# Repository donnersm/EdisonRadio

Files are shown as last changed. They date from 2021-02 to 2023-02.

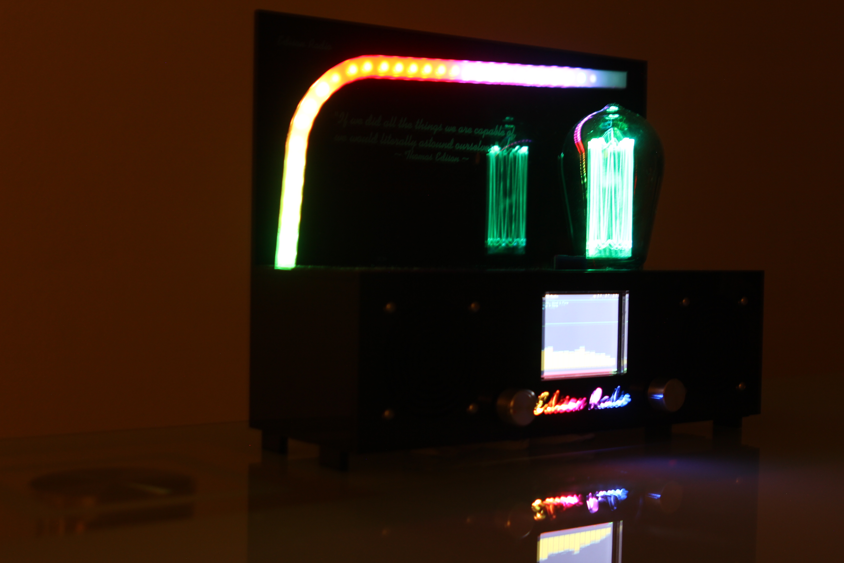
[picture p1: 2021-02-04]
Photos/IMG_9397.JPG

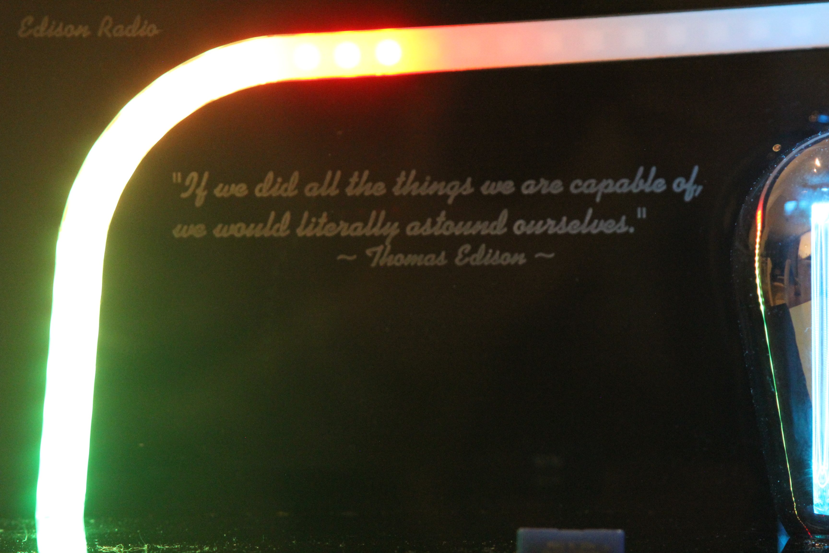
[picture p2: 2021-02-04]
Photos/IMG_9385.JPG

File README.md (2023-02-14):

# EdisonRadio
Internet Radio ESP32 based on Ed's Smallenburg's version but with some enhancements
You'll find all the information about firmware hardware, web interface, building instruction etc. in the documentation folder

If you are using the same hardware wiring as me...you can also upload the pre compiled sketch ( bin file) directly to your ESP32
https://donnersm.github.io/EdisonRadio/flash.html
Use edge or chrome browser for this to work and before you upload, run the init sketch once...

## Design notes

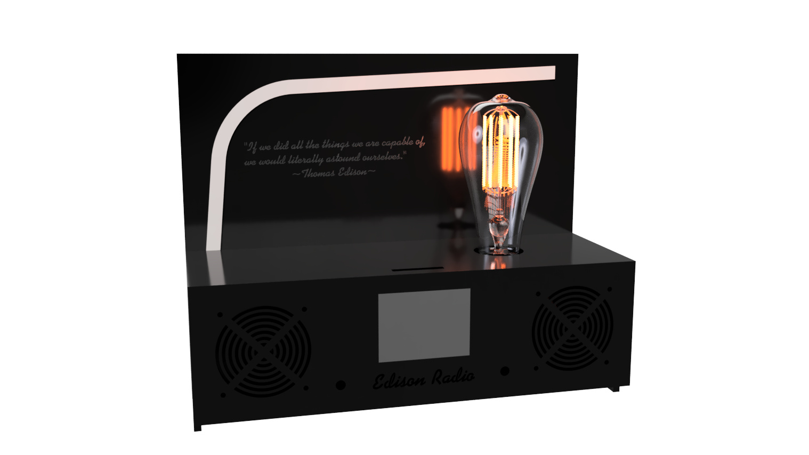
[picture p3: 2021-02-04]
Photos/radio_2021-Jan-22_03-03-24PM-000_CustomizedView857531055_jpg.jpg

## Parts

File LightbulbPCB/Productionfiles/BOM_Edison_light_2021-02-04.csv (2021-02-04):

ID | Name | Designator | Footprint | Quantity | Manufacturer Part | Manufacturer | Supplier | Supplier Part | LCSC Assembly | JLCPCB SMD
1 | WS2812B | LED1,LED2,LED3,LED4 | LED-SMD_4P-L5.0-W5.0-TL | 4 | WS2812B | Worldsemi | LCSC | C114585 | Yes
2 | 2*2P header | H1 | HDR-TH_4P-P2.54-H-R2-C2-S2.54-W10.0 | 1 | 2*2P header | BOOMELE | LCSC | C60561
3 | 100nF | C1 | C1206 | 1 | CL31B104KBCNNNC | SAMSUNG | LCSC | C24497 |  | Yes

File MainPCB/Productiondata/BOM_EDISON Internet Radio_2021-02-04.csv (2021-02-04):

ID | Name | Designator | Footprint | Quantity | Manufacturer Part | Manufacturer | Supplier | Supplier Part | JLCPCB SMD | LCSC Assembly
1 | VS1053B | U7 | LQFP-48_L7.0-W7.0-P0.50-LS9.0-BL | 1 | VS1053B | VLSI | LCSC | C9922 | Yes
2 | 22pF | C24,C25 | C0805 | 2 | CL21C220JBANNNC | SAMSUNG | LCSC | C1804 | Yes
3 | MC7805ABD2TR4G | U3 | TO-263-2_L10.0-W9.1-P5.08-LS15.2-TL | 1 | MC7805ABD2TR4G | ON | LCSC | C152462 | Yes
4 | 470uF | C9 | CAP-SMD_BD8.0-L8.3-W8.3-RD | 1 | VZH471M1CTR-0810 | LELON | LCSC | C164069 | Yes
5 | RS3MB | D1,D2 | SMB_L4.6-W3.6-LS5.3-RD | 2 | RS3MB | Shandong Jingdao Microelectronics | LCSC | C123923 | Yes
6 | 100nF | C22,C7,C11,C10,C4,C15,C16,C27,C28,C29,C31,C32,C34,C26 | C0805 | 14 | CC0805KRX7R9BB104 | YAGEO | LCSC | C49678 | Yes
7 | 100K | R19,R16,R13,R11,R12,R14,R15 | R0805 | 7 | 0805W8F1003T5E | UniOhm | LCSC | C17407 | Yes
8 | MCP1703T-3302E/MB | U5 | SOT-89-3_L4.5-W2.5-P1.50-LS4.2-BR | 1 | MCP1703T-3302E/MB | MICROCHIP | LCSC | C27287 | Yes
9 | 10uF | C3,C1 | C0805 | 2 | CL21A106KAYNNNE | SAMSUNG | LCSC | C15850 | Yes
10 | 470 | R7,R1,R4,R5 | R0805 | 4 | 0805W8F4700T5E | UniOhm | LCSC | C17710 | Yes
11 | PAM8403DR_C348830 | U8 | SOP-16_L10.3-W5.4-P1.27-LS7.8-BL | 1 | PAM8403DR | Diodes Incorporated | LCSC | C348830 | Yes
12 | 10 | R10 | R0805 | 1 | 0805W8F100JT5E | UniOhm | LCSC | C17415 | Yes
13 | kf2510_3A | H7,H6,H9,H10 | CONN-TH_3P-P2.00_KF2510_3A | 4 | kf2510_3A | BOOMELE | LCSC | C29275
14 | 22 | R8,R2 | R0805 | 2 | 0805W8F220JT5E | UniOhm | LCSC | C17561 | Yes
15 | Header-Male-2.54_1x3 | H3 | HDR-TH_3P-P2.54-V | 1 | Header2.54mm 1*3P | BOOMELE | LCSC | C49257
16 | 22272061 | H1 | CONN-TH_22272061 | 1 | 22272061 | MOLEX | LCSC | C504992
17 | DG308-2.54-04P-14-00A(H) | U2 | CONN-TH_DG308-2.54-04P-14-00A-H | 1 | DG308-2.54-04P-14-00A(H) | DEGSON | LCSC | C708735
18 | 470nF | C23,C21 | C0805 | 2 | CL21B474KBFNNNE | SAMSUNG | LCSC | C13967 | Yes
19 | 10uF | C14,C17,C18,C20,C5,C12 | CAP-SMD_L3.2-W1.6-R-RD | 6 | TAJA106K016RNJ | AVX | LCSC | C7171 | Yes
20 | 470uF | C19 | CAP-SMD_BD6.3-L6.6-W6.6-FD | 1 | VZH471M0JTR-0607 | LELON | LCSC | C134834 | Yes
21 | Header-Male-2.54_2x3 | J1 | HDR-TH_6P-P2.54-V-R2-C3-S2.54 | 1 | Header-Male-2.54_2x3 | BOOMELE | LCSC | C65114
22 | 22-27-2081 | H11 | CONN-TH_22-27-2081 | 1 | 22-27-2081 | MOLEX | LCSC | C240822
23 | Header-Male-2.54_1x1 | P1 | HDR-TH_1P-P2.54-V-M | 1 | Header-Male-2.54_1x1 | ReliaPro | LCSC | C81276
24 | 1M | R20 | R0805 | 1 | 0805W8F1004T5E | UniOhm | LCSC | C17514 | Yes
25 | T2A | FH1 | FUSE-TH_BD9.5-P5.08-D1.0 | 1 | 56000001009 | Littelfuse | LCSC | C142909
26 | 15 | R6 | R0805 | 1 | 0805W8F150JT5E | UniOhm | LCSC | C17480 | Yes
27 | ESP32_DevKit_V1_DOIT-ESP32_DevKit_V1_DOIT | U1 | ESP32_DEVKIT_V1_DOIT | 1
28 | EE14 | L2,L1 | EE14_TRANSFORMER | 2 | EE14 | Unknown | Alieexpress | EE14
29 | KF128-2.54-2P | U4 | CONN-TH_P2.54_KF128-2.54-2P | 1 | KF128-2.54-2P | Cixi Kefa Elec | LCSC | C474920
30 | Header-Male-2.54_1x2 | H2,H4 | HDR-TH_2P-P2.54-V | 2 | 826629-2 | TE Connectivity | LCSC | C86471
31 | 10K | R9,R3,R18,R17 | R0805 | 4 | 0805W8F1002T5E | UniOhm | LCSC | C17414 | Yes
32 | MCP1700T-1802E/TT | U6 | SOT-23-3_L2.9-W1.3-P1.90-LS2.4-BR | 1 | MCP1700T-1802E/TT | MICROCHIP | LCSC | C150796 | Yes
33 | 47nF | C8 | C0805 | 1 | CL21B473KBCNNNC | SAMSUNG | LCSC | C53134 | Yes
34 | KF2510-5A | H8 | CONN-TH_5P-P2.54_KF2510-5A | 1 | KF2510-5A | BOOMELE | LCSC | C27544
35 | 1uF | C13 | C0805 | 1 | CL21B105KBFNNNE | SAMSUNG | LCSC | C28323 | Yes
36 | 33 | R21,R22 | R0805 | 2 | 0805W8F330JT5E | UniOhm | LCSC | C17634 | Yes | Yes
37 | 12.288MHz | X1 | HC-49S_L11.4-W4.8 | 1 | 6CS12288F20UCG | SHENZHEN CRYSTAL TECH | LCSC | C252314
38 | 10nF | C6,C2 | C0805 | 2 | CL21B103KBANNNC | SAMSUNG | LCSC | C1710 | Yes

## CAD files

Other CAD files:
Autocad/allplates.dwg
Fusion360/radio v21.f3d

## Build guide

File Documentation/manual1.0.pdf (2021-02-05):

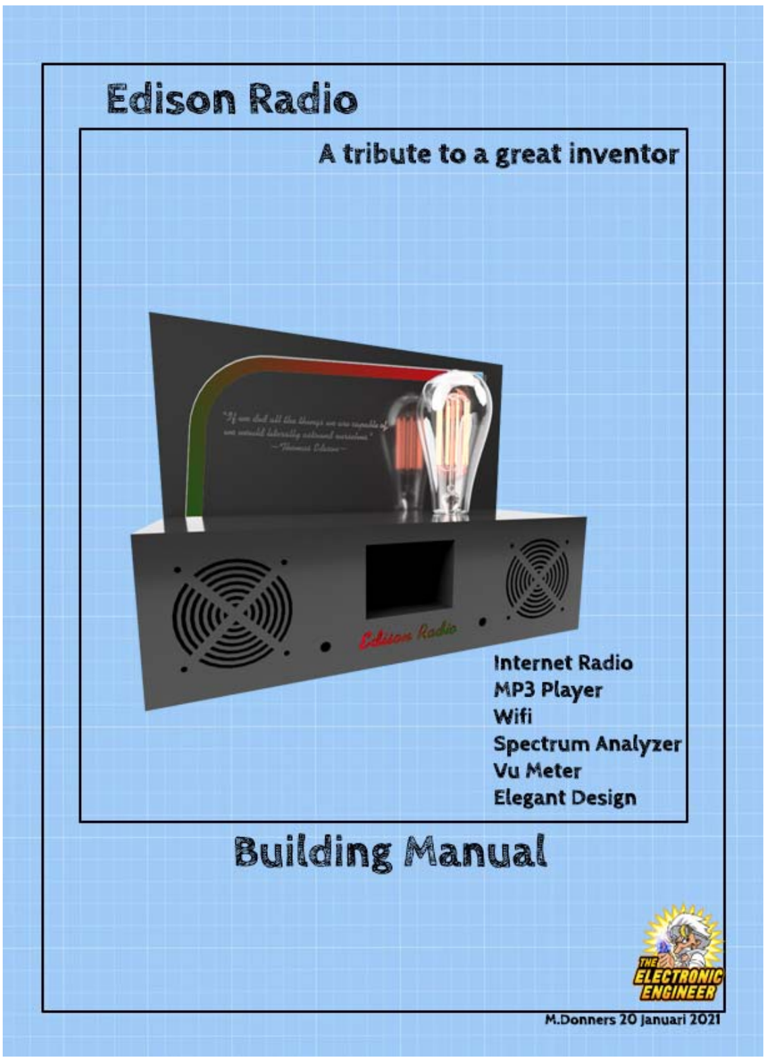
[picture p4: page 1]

## Table of Contents

M Donners Document version 1.0

## 1. Disclaimer and safety

I, Mark Donners, The Electronics Engineer, may or may not endorse various Do‐It‐Yourself (DIY) projects and all DIY projects are purely “at your own risk”. As with any DIY project, unfamiliarity with the tools and process can be dangerous. Posts should be construed as theoretical advice only.

If you are at all uncomfortable or inexperienced working on these projects (especially but not limited to electronics and mechanical), please reconsider doing the job yourself. It is very possible (but not likely) on any DIY project to damage belongings or void your property insurance, create a hazardous condition, or harm or even kill yourself or others.

I will not be held responsible for any injury due to the misuse or misunderstanding of any DIY project.

By using the information provided by me, (Website,Youtube, facebook and other social media), you agree to indemnify me, affiliates, subsidiaries and their related companies for any and all claims, damages, losses and causes of action arising out of your breach or alleged breach of this agreement(disclaimer).

The materials on this site are distributed “as is” and appear on the site without express or implied warranties of any kind, except those required by the relevant legislation. In particular, I make no warranty as to the accuracy, quality, completeness or applicability of the information provided.

The information provided is for entertainment and promotional purposes only. You may not rely on any information and opinions expressed in it for any other purpose.

Disclaimer short version:

This is a DIY project, use any provided information and/or materials at your own risk! I am not responsible for what you do with it!

## 2. About this project

This project is bases on the internet radio by Ed Smallenburg. He did an awesome job in creating a working internet‐based radio. He shared his coding and hardware on the world wide web so that people like you and me can learn from it. He shared his build on GitHub using the copyleft license. (It basically comes down to: use it, modify it as needed, don't copyright it and share….)

You can find Ed's original build and data here:

Edzelf/ESP32‐Radio: Internet radio based on ESP32, VS1053 and a TFT screen. (github.com)

So, I started with Ed's Arduino sketch and I added a few extra options:

- Search engine to find Internet Radio station by country.
- Find and implement the station's Logo and display it on the browser interface.
- Spectrum analyser on the TFT Screen
- LED VU meter with Pixel leds WS2812
- Sliders for changing Audio Settings.

The modified software and all project data will be available here:

https://github.com/donnersm/EdisonRadio

TIP: download all with one click by pressing the green button and choosing "download ZIP"

As you might have noticed, this project is named the Edison Radio. Thomas Edison was a great inventor who, amongst other things, improved the microphone for telephones by developing a carbon microphone. In ways, more than one, Edison contributed to worldwide communication. However, his greatest invention was not this carbon microphone or even his well‐known phonograph but, it was the invention of the light bulb by far! Without Edison, we might still be using candles to bring light in darkness. That is why this radio has a light bulb as centrepiece. .. O yeah, this 100% optional attribute also looks kind of cool

3. Tools needed.

You will be working with low voltage (5V max) but you should know your way around basic electronics. Using the wrong voltage or polarity might kill your project in an instance!

Being successful in building this device requires some adequate skills and tools. You should be able to solder small components on a PCB which will require a soldering station with a small tip as you will be handling components like 0805 sized and a LQFP‐48 package. If this is beyond your possibilities, then you should ask someone to do it for you or order an already assembled PCB.

(Availability will depend on demand).

Furthermore, you be programming the microcontroller by using the Arduino IDE environment. Although the steps to do so will be described in this document, it is advisable for you to get to know this Arduino software.

If you are considering building the Edison housing, you will need to produce the panels for it. It can be done by hand, but it would be best to use a Laser cutter. Remember, there are some companies that offer a laser cutting service. Maybe there is a company near you who can do it for you?

And yes, you will need some basic tools like a screwdriver

## 4. Hardware

## 4.1. Main PCB

The pcb without components is available at my Tindie store here: Tindie.

Shipping is only possible within the EU because shipping to other countries will involve import Tax, declarations of conformity and other complicated stuff. Nobody is looking for that kind of complicated formalities or import tax upon receiving the goods. If you are a resident of a country that I don’t ship to, you can always order a pcb directly from a PCB supplier near you. The Gerber productions files you need for that are available for download, although it might be more expensive than what you are hoping for. If you need 1 or 2 PCB’s, a Tindie order is the cheapest way to go.

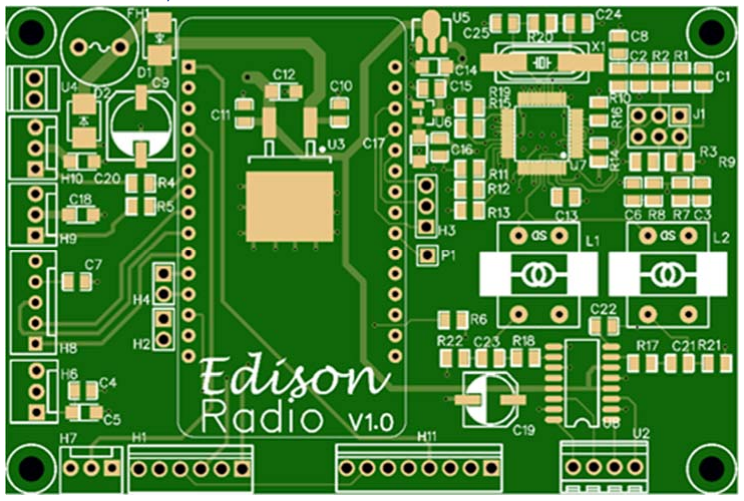
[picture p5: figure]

4.1.1. Assembly

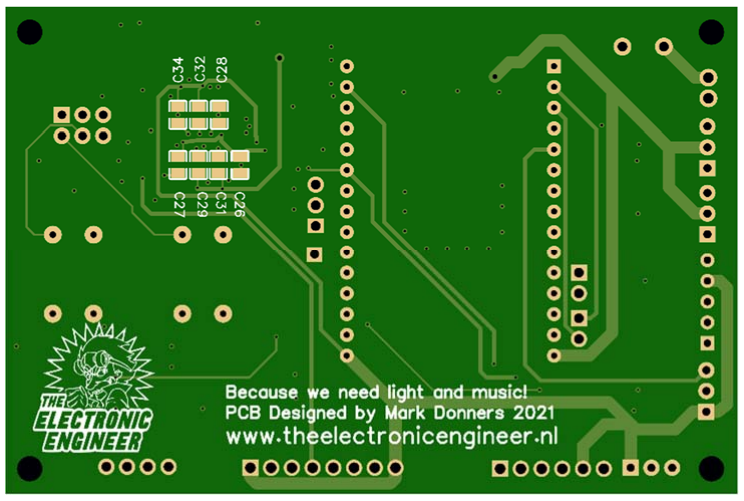
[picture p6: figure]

Assembly notes:

- Assembly of the bottom side are not that difficult all the only components on the bottom are 100nf smd 0805 capacitors (C26,27,28,29,31,32,34)
- Make sure you have the orientation of specific components correct. Resistors and ceramic capacitors are not critical but Electrolytic capacitors and semiconductors have to go on the right way! Do not mix up Cathode and Anode.
- The audio transformers L! and L2 also have an orientation. Make sure to align the letters 'SD' or dot, with the silkscreen of the PCB. WARNING, I encountered several versions that had this marking on the wrong side of the transformer. This makes it hard to tell which side is primary and which side is secondary. Best is to try it. If you solder everything else first, you can connect a speaker and play some music. You can then simply try what way to mount the transformers. Or use a socket so it is easy to reverse when necessary. When mounted correctly, a clear sound will be what you hear but if it is reversed, all you will hear is digital noise.
- I Used MOLEX connectors and headers but you can use any type you like if it fits the PCB. The raster used is 2.54"
- Connectors H2, H4, H3 and P1 can be left out. Those are connected to the unused pins of the ESP32 board in case I need them later for experimenting and debugging.
- Use a socket for the fuse and for the ESP32. A socket makes swopping them a lot easier.
- In my experience, it works best to assemble U7 and U8 before the rest. U7 might be the most difficult of the whole PCB and you will need a steady hand as well as experience in soldering SMD components. Safe all the connectors for last.

Here are some links for some of the used components. A more detailed list of components is available on one of the following pages of this document.

ESP32 controller

https://nl.aliexpress.com/item/4000152270368.html?spm=a2g0s.9042311.0.0.1ec64c4ddCHl0d

Audio transformer

https://nl.aliexpress.com/item/32913784557.html?spm=a2g0s.9042311.0.0.27424c4d6fwORq

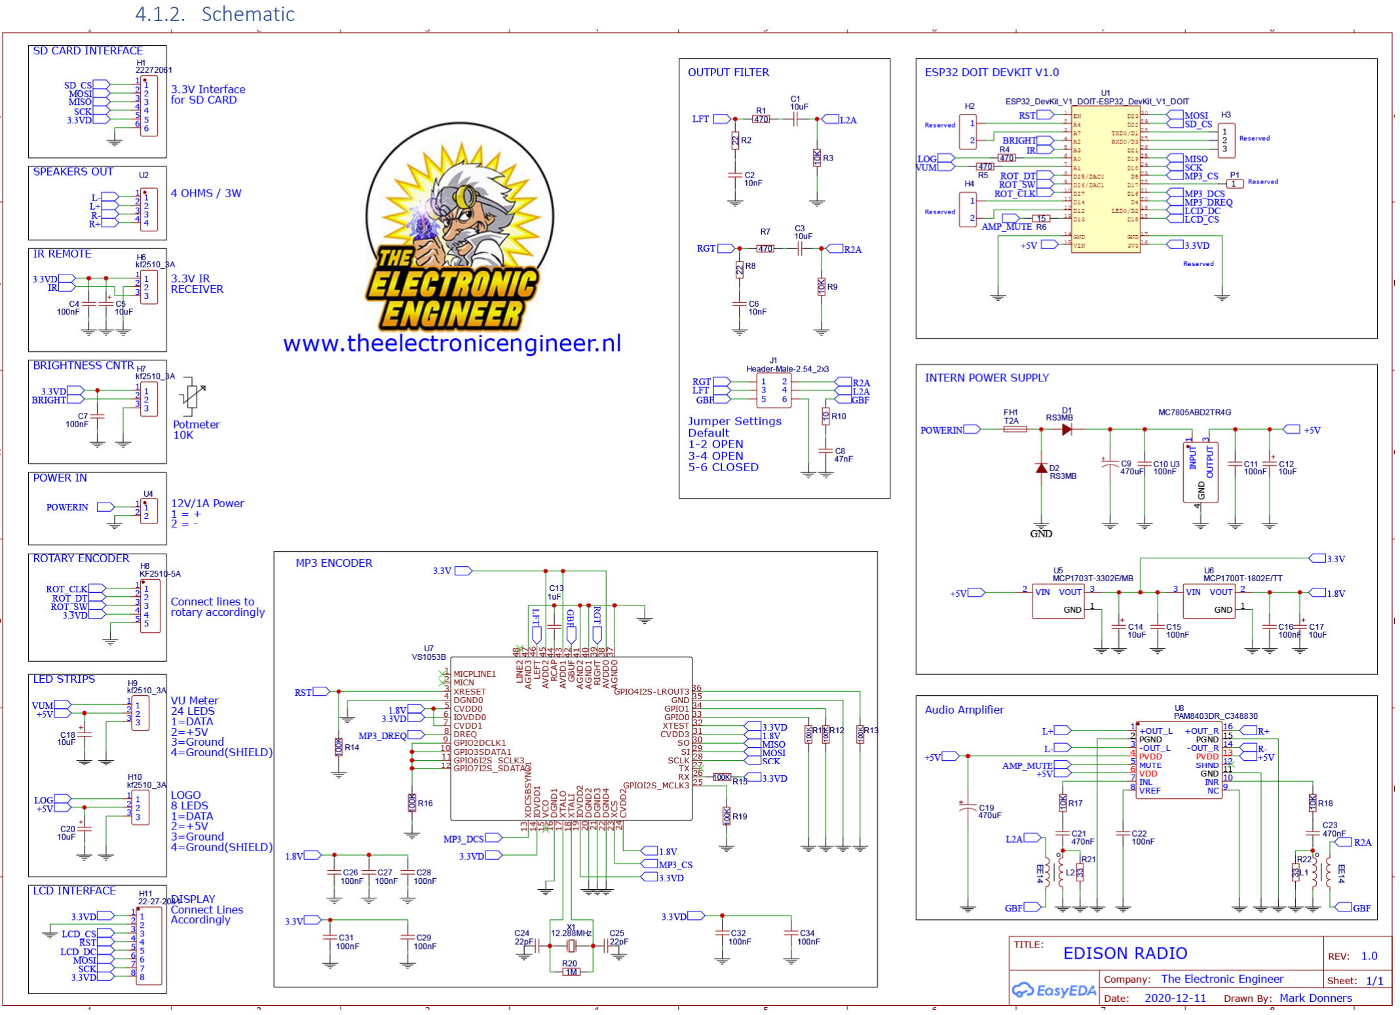
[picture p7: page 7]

Page | 7
4.1.2. Schematic

4.1.3. PCB Part list main PCB
The complete part list for the main component is here:
Designator | Name | Footprint | Quantity | Manufacturer Part | Manufacturer | Supplier | Supplier Part
C13 | 1uF | C0805 | 1 | CL21B105KBFNNNE | SAMSUNG | LCSC | C28323
C14,C17,C18,C20,C5,C12 | 10uF | CAP‐SMD_L3.2‐W1.6‐R‐RD | 6 | TAJA106K016RNJ | AVX | LCSC | C7171
C19 | 470uF | CAP‐SMD_BD6.3‐L6.6‐W6.6‐FD | 1 | VZH471M0JTR‐0607 | LELON | LCSC | C134834
C22,C7,C11,C10,C4,C15,C16,C27,
C28,C29,C31,C32,C34,C26 | 100nF | C0805 | 14 | CC0805KRX7R9BB104 | YAGEO | LCSC | C49678
C23,C21 | 470nF | C0805 | 2 | CL21B474KBFNNNE | SAMSUNG | LCSC | C13967
C24,C25 | 22pF | C0805 | 2 | CL21C220JBANNNC | SAMSUNG | LCSC | C1804
C3,C1 | 10uF | C0805 | 2 | CL21A106KAYNNNE | SAMSUNG | LCSC | C15850
C6,C2 | 10nF | C0805 | 2 | CL21B103KBANNNC | SAMSUNG | LCSC | C1710
C8 | 47nF | C0805 | 1 | CL21B473KBCNNNC | SAMSUNG | LCSC | C53134
C9 | 470uF | CAP‐SMD_BD8.0‐L8.3‐W8.3‐RD | 1 | VZH471M1CTR‐0810 | LELON | LCSC | C164069
D1,D2 | RS3MB | SMB_L4.6‐W3.6‐LS5.3‐RD | 2 | RS3MB | Shandong Jingdao ME | LCSC | C123923
FH1 | T2A | FUSE‐TH_BD9.5‐P5.08‐D1.0 | 1 | 56000001009 | Littelfuse | LCSC | C142909
H1 * | 22272061 | CONN‐TH_22272061 | 1 | 22272061 | MOLEX | LCSC | C504992
H11 * | 22‐27‐2081 | CONN‐TH_22‐27‐2081 | 1 | 22‐27‐2081 | MOLEX | LCSC | C240822
H2,H4 * | Header‐Male‐2.54_1x2 | HDR‐TH_2P‐P2.54‐V | 2 | 826629‐2 | TE Connectivity | LCSC | C86471
H3 * | Header‐Male‐2.54_1x3 | HDR‐TH_3P‐P2.54‐V | 1 | Header2.54mm 1*3P | BOOMELE | LCSC | C49257
H7,H6,H9,H10 * | kf2510_3A | CONN‐TH_3P‐P2.00_KF2510_3A | 4 | kf2510_3A | BOOMELE | LCSC | C29275
H8 | KF2510‐5A | CONN‐TH_5P‐P2.54_KF2510‐5A | 1 | KF2510‐5A | BOOMELE | LCSC | C27544
J1 | Header‐Male‐2.54_2x3 | HDR‐TH_6P‐P2.54‐V‐R2‐C3‐S2.54 | 1 | Header‐Male‐2.54_2x3 | BOOMELE | LCSC | C65114
L2,L1 | EE14 | 1300:8 Ohm audio transformer | 2 | 1E0836 | OOTDTY | Alieexpress | EE14
P1 * | Header‐Male‐2.54_1x1 | HDR‐TH_1P‐P2.54‐V‐M | 1 | Header‐Male‐2.54_1x1 | ReliaPro | LCSC | C81276
R10 | 10 | R0805 | 1 | 0805W8F100JT5E | UniOhm | LCSC | C17415
R19,R16,R13,R11,R12,R14,R15 | 100K | R0805 | 7 | 0805W8F1003T5E | UniOhm | LCSC | C17407
R20 | 1M | R0805 | 1 | 0805W8F1004T5E | UniOhm | LCSC | C17514
R21,R22 | 33 | R0805 | 2 | 0805W8F330JT5E | UniOhm | LCSC | C17634
R6 | 15 | R0805 | 1 | 0805W8F150JT5E | UniOhm | LCSC | C17480
R7,R1,R4,R5 | 470 | R0805 | 4 | 0805W8F4700T5E | UniOhm | LCSC | C17710
R8,R2 | 22 | R0805 | 2 | 0805W8F220JT5E | UniOhm | LCSC | C17561
R9,R3,R18,R17 | 10K | R0805 | 4 | 0805W8F1002T5E | UniOhm | LCSC | C17414
U1 | DOIT DEVKIT ESP32 V1 | custom DOIT DEVKIT ESP32 V1 | 1 | | | Alieexpress
U2 * | DG308‐2.54‐04P‐14‐00A(H) | CONN‐TH_DG308‐2.54‐04P‐14‐00A‐H | 1 | DG308‐2.54‐04P‐14‐00A(H) | DEGSON | LCSC | C708735
U3 | MC7805ABD2TR4G | TO‐263‐2_L10.0‐W9.1‐P5.08‐LS15.2‐TL | 1 | MC7805ABD2TR4G | ON | LCSC | C152462
U4 * | KF128‐2.54‐2P | CONN‐TH_P2.54_KF128‐2.54‐2P | 1 | KF128‐2.54‐2P | Cixi Kefa Elec | LCSC | C474920
U5 | MCP1703T‐3302E/MB | SOT‐89‐3_L4.5‐W2.5‐P1.50‐LS4.2‐BR | 1 | MCP1703T‐3302E/MB | MICROCHIP | LCSC | C27287
U6 | MCP1700T‐1802E/TT | SOT‐23‐3_L2.9‐W1.3‐P1.90‐LS2.4‐BR | 1 | MCP1700T‐1802E/TT | MICROCHIP | LCSC | C150796
U7 | VS1053B | LQFP‐48_L7.0‐W7.0‐P0.50‐LS9.0‐BL | 1 | VS1053B | VLSI | LCSC | C9922
U8 | PAM8403DR_C348830 | SOP‐16_L10.3‐W5.4‐P1.27‐LS7.8‐BL | 1 | PAM8403DR | Diodes Incorporated | LCSC | C348830
X1 | 12.288MHz | HC‐49S_L11.4‐W4.8 | 1 | 6CS12288F20UCG | SHENZHEN CRYSTAL
| | | | | TECH | LCSC | C252314
* = You can use any header that fits the PCB 2,54 raster. Header ,, ,, ,, are optional, you cn leave them out, the only function for that header is debugging or future options.
I would recommend that you solder the Fuse in a socket for easy exchange when things go south….the same goes for the ESP32 controller board.

## 4.2. Optional Light Bulb and PCB

To give this radio more of an “Edison” look I decided to implement the optical illusion of a Edison Light Bulb. It is optional and without it, the radio will function just fine. However, this ornament justifies the name of this radio. Doesn’t it? You can leave it out but, you will be missing out on this very cool looking tribute to the world's best inventor.

The light bulb is actually a modified decorative LED light. ( Edison Light Bulb) The one I bought is from CALEX holland and is called the E27 Titanium Rustic Lamp art. 473894

https://www.partsnl.nl/led‐glasfiber‐titanium‐st64‐rustieklamp‐35w‐e27‐dimbaar‐473894

There are several models available and you might have to adjust your wiring and voltage supply if you decide to buy a different light bulb.

The one I bought was surprisingly easy to modify to my needs. Basically, you can unscrew the outer glass and take out the inner part and socket. I then pulled out the inner cylinder from it's socket by force and removed the LED PCB from the socket. I then saw off the lower part (lamp foot)and re‐attached the cylinder to the socket so that it screws back into the outer glass bulb. So, this leaves me with the outer light bulb and the inner cylinder in place. The only difference is that now, the bottom of the cylinder is open and I can attach a small PCB with pixel LEDS to it.

Basically, this PCB only contains 4 pixel LEDS WS2812B and an optional connector or wire input. You can look at it as a ledstrip of 4 LEDS that you can connect serially with the Logo ledstrip. The LEDS can be purchased here:

https://www.banggood.com/10pcs‐RGB‐WS2812B‐4Pin‐Full‐Color‐Drive‐LED‐Lights‐CJMCU‐for‐Arduino‐products‐that‐ work‐with‐official‐Arduino‐boards‐p‐1103143.html

Make sure you place those LEDS in the correct orientation. There is a marked corner on the silkscreen for each LED that must match with the marking on the LED’s. The light bulb PCB will be connected to the WS2812B‐LED Strip that is used with the Logo. If you don't use the logo, you can connect the light bulb PCB directly to the main PCB logo Ledstrip connector.

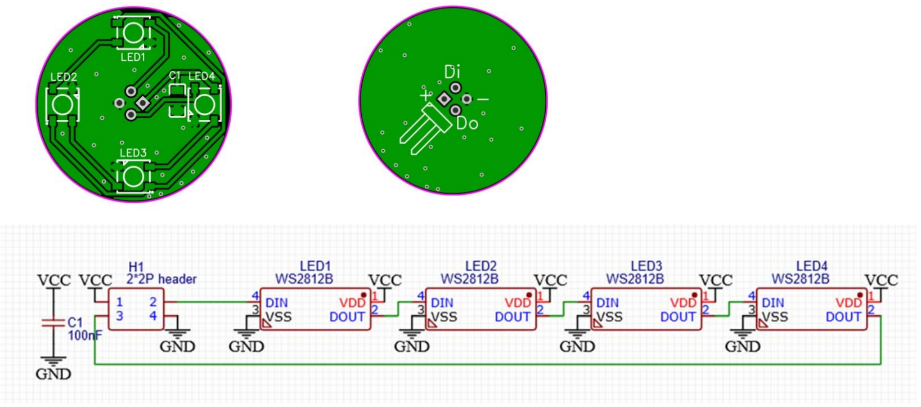
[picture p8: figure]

Designator | Name | Footprint | Quantity | Manufacturer Part | Manufacturer | Supplier | Supplier Part
LED1,LED2,
LED3,LED4 | WS2812B | LED‐SMD_4P‐L5.0‐W5.0‐TL | 4 | WS2812B | Worldsemi | LCSC | C114585

H1 | 2*2P header | HDR‐TH_4P‐P2.54‐H‐R2‐C2‐S2.54‐W10.0 | 1 | 2*2P header | BOOMELE | LCSC | C60561
C1 | 100nF | C1206 | 1 | CL31B104KBCNNNC | SAMSUNG | LCSC | C24497

## 4.3. Interface components

Ok, so you got a finished PCB? Good! Now it is time to add the surrounding components

You’ll need:

Potentiometer
1 potentiometer. This can by any potentiometer with a value between 1K and 50K. A value below 1K is not recommended because of the current it will consume. A value beyond 50K will work but might cause too much noise. I prefer to use a potentiometer with a linear scale of 10K and I choose one that has a switch so that I can use this as a power switch to turn on/off the radio.

Rotary switch
I use a rotary switch for basic operation of the radio. This is optional but if you decide not to use it, you’ll have to adjust the configuration file using the browser interface. ( More of that later). The rotary switch I used is the one that comes with most Arduino sensor kids and can also be obtained here: https://www.banggood.com/KY‐040‐Rotary‐Decoder‐Encoder‐Module‐AVR‐PIC‐p‐914010.html?cur_warehouse=CN&rmmds=search

Speakers
The PCB has an onboard amplifier that can handle 2 speakers of 3W / 4Ω. I used these speakers: Visaton FR7 2.5”art. 305266

https://www.conrad.nl/p/visaton‐fr‐7‐25‐inch‐64‐cm‐breedband‐luidsprekerchassis‐5‐w‐4‐305266

Display
You can choose from several different displays but you’ll have to adjust the firmware accordingly. I used a ILI9341 240 x 320 LCD: (This is the default setting):

https://www.banggood.com/2_8‐Inch‐ILI9341‐240x320‐SPI‐TFT‐LCD‐Display‐Touch‐Panel‐SPI‐Serial‐Port‐Module‐p‐ 1206782.html

VU‐Meter LEDSTRIP
the ledstrip to be used for the Vu‐Meter is a WS2812B based Ledstrip. You’ll have to adjust the firmware to match the number of leds you’ll use. Default it is set to 24. I used a ledstrip 96leds/meter:

https://nl.aliexpress.com/item/4001222557975.html?spm=a2g0s.9042311.0.0.27424c4dKZDVlW

Logo leds
I used some of the Vu‐ meter ledstrip to illuminate the logo. The Logo Ledstrip has to be connected serially with the Light Bulb PCB.

4.4. Acrylic Laser cut Casing.

Although I might not be completely neutral in this matter, I believe that this 'EDISON' Design is very cool and elegant looking…..Wouldn't you want one? If you do, feel free to download the AutoCAD files to 'laser cut' or mechanically engineer your own. It is fine if you prefer to modify that design or use your own creation instead but know that me design is freely available.

I used a laser cutter to cut all the acrylic parts (5mm thickness) for this casing. The space that is to be filled with the VU meter has a plastic cover made of 1mm transparent or 'milk' acrylic that is glued into place. Using a milky colour will defuse the light to look more elegant fluent. You can experiment with different colours of (semi) transparent cut out acrylic to find whatever gives you the best vibe.

All the parts of the casing are glued together using proper glue for the used materials.

Except for the bottom plate what is hold in place by two small screws.

## 5. Assembly

When you have all the components and parts, you can start the assembly.

## 5.1. Casing

The bottom panel is the only panel that is hold in place by two screws. All other panels are glued into place with acrylic glue. I used Acrifix(1R0192) but your local store might have something similar.

The first step is to glue the backplate of the ledstrip onto the back panel. You can also mount the LCD protection glass if you decide to use it. You will have to experiment with the size because it depends on the size of your cutters' laser beam. I designed mine to be 0,5mm larger in width and height to compensate for it. That way it will fit in place perfectly.

Tip: To assemble and glue everything together, a solid 90° angle will help. I use a metal profile and some clamps as support.

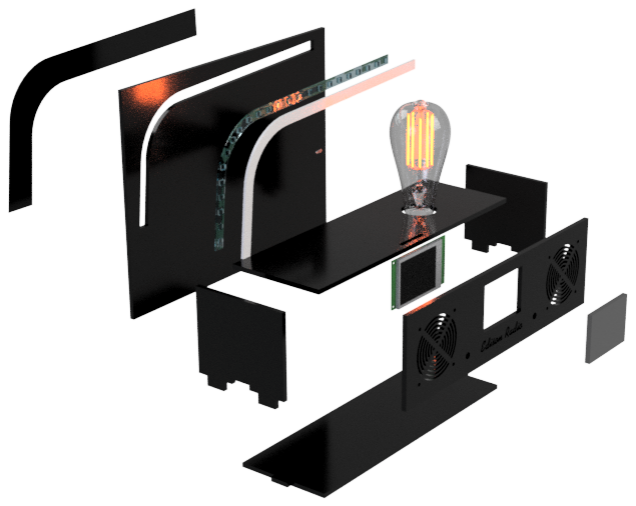
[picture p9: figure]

## 5.2. Mounting everything in its place

This is what I Did:

‐ | First, I glued the front top and sides together.
‐ | I mounted the display, speakers, potmeter, rotary switch, power switch and power entry.
‐ | I started wiring as much as possible.
‐ | I mounted the main PCB to the bottom plate.
‐ | I glued the whole assembly to the backplate.
‐ | I connected the wires to the PCB.
‐ | This would be the time to program your ESP32.
‐ | Test It!
‐ | Close it up by attaching the bottom plate with two little screws.
‐ | I had no use for operating switches or IR receiver. But, you can implement it if you like.

## 5.3. Wiring

The wiring is not that spectacular. The internal wire to connect the power input to the main PCb should be thick enough to handle about 3A. The Gnd and power wire to the LEDStrips should be able to handle 1A. The rest is not that big of a deal. However, I did twist the speaker wires by channel. It's an old habbit. The rest of the wires I bound together using some straps like T‐Raps. Just follow the wiring diagram.

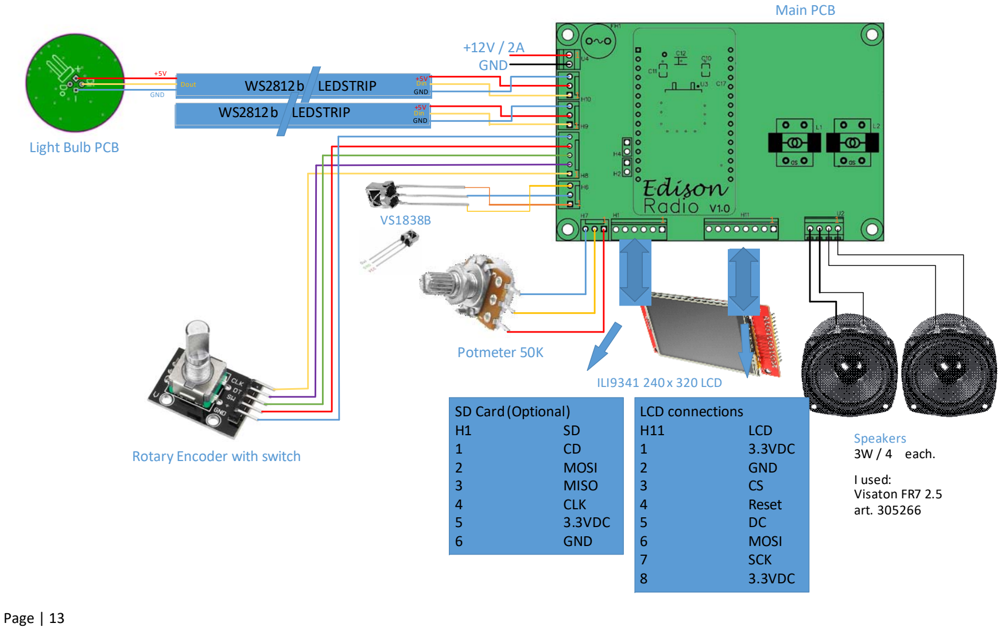
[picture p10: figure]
Page | 13; SD Card (Optional); MOSI; MISO; CLK; 3.3VDC; GND; +12V / 2A GND; WS2812b LEDSTRIP; Dout; Din +5V; LCD connections; LCD; Reset; SCK; ILI9341 240 x 320 LCD; Speakers 3W / 4 each.; I used: Visaton FR7 2.5 art. 305266; Rotary Encoder with switch; Light Bulb PCB; Main PCB; Potmeter 50K

## 6. Software

## 6.1. Firmware

6.1.1. Dual Core usage ESP32
The ESP32 DOIT bord is operating at 160Mhz and it has a dual core! One core is used for streaming the audio to the VS1053 Decoder while the other core is used for all other activities like user interface, Spectrum analyser and webserver.
6.1.2. Firmware sections
The firmware can be divided into several sections:

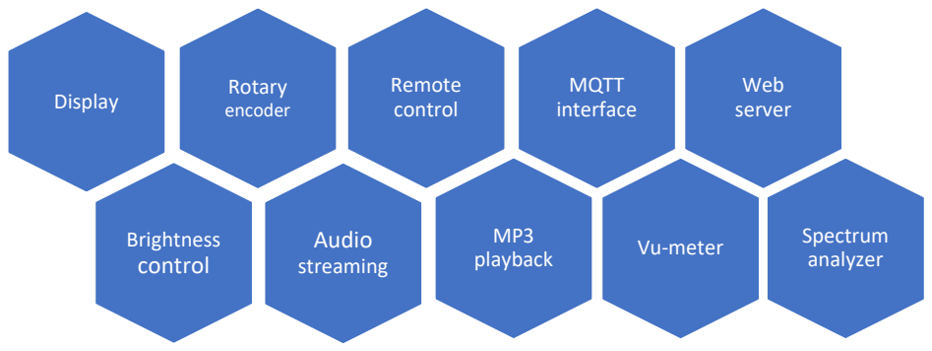
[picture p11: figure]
Rotary encoder Display; MP3 playback; Audio streaming; Web server; Remote control; MQTT interface; Brightness control; Spectrum analyzer Vu‐meter

Display

Rotary Encoder

The rotary encoder switch can control some essential functions of the ESP32‐radio.

The default function is volume control. Turning the knob will result in lower or higher volume. Pressing the knob will mute/unmute the signal. The text “Mute” or “Unmute” will be shown on the TFT during 4 seconds.

A double click selects the preset‐mode. Rotation of the switch will select one of the preset stations. The preset will be shown on the TFT. Once a preset is selected, you can activate this preset by a single click.
Without rotation, the next preset is selected.

A triple click will select the mp3‐player (SD card required). Rotation of the switch will select one of the tracks on the SD card. The track will be displayed on the TFT. Once a track is selected, you can activate it by a single click.
Without rotation, the next track is selected.
After the triple click the player stops, as reading filenames will overload the SD card I/O.

A long click ( longer than 1 second ) will start playing random tracks from SD card.

After an inactivity of 4 seconds the rotary encoder will return to its default function (VOLUME).

IR Remote Control
Several commands van be linked to any remotecode. While the program is running, a code received by the IR receiver is interpreted by the software as a command if that command is defined in the configuration file.

The radio can be controlled by an IR remote control like this:

To use this interface VS1838B receiver must be connected to Connector H6 of the Edison main PCB

Add the assigned GPIO pin to the preferences through the config page in the web interface
pin_ir = 35 | # GPIO Pin number for IR receiver VS1838B
The software will read the raw code of the IR transmitter, making it possible to use virtually any remote control to be used. I tested it with the 21 button remote as well as with an LG TV remote.
To assign functions to the buttons, watch the debug log output while pressing a button. For example, press the +volume button. You will see something like:
D: IR code 807F received, but not found in preferences!
Now add the command:
ir_807F = upvolume = 2
to the preferences in the config page of the web interface. Likewise you can assign functions to all buttons, for example:
ir_8A31 = uppreset = 1
ir_719A = station = us1.internet-radio.com:8105
ir_1F6B = mute

MQTT interface
Please take a look at the original coding documentation by ED:

https://github.com/Edzelf/ESP32‐Radio/tree/master/doc

Web Server

Please take a look at the original coding documentation by ED:

https://github.com/Edzelf/ESP32‐Radio/tree/master/doc

Brightness Control

A Potentiometer is used to controll the brightness of the logo and optional light Bulb. While running, the code will look at the voltage at the potmeter Pin D34 to convert it into a level of brightness.

Audio streaming

One core is dedicted to communicate with the VS1053 chip and ensures a smooth audio stream.

Mp3 playback

If connected, MP3 files that are stored on a SD card can be played.

Vu‐Meter

The Vu‐meter shows a live interpretation of the Spectrum analyzer data to display the sound level of the audio stream at any given time.

Spectrum Analyzer

The spectrum analysis is done by a plugin that is loaded onto the VS1053 chip. The code retrieves the live data from the VS1053 and update's the LCD screen accordingly.

6.1.3. Operating the radio without webinterface
Rotary encoder ( Right knob)
The default function is volume control. Turning the knob will result in lower or higher volume. Pressing the knob will mute/unmute the signal. The text “Mute” or “Unmute” will be shown on the TFT during 4 seconds.

A double click selects the preset‐mode. Rotation of the switch will select one of the preset stations. The preset will be shown on the TFT. Once a preset is selected, you can activate this preset by a single click.
Without rotation, the next preset is selected.

A triple click will select the mp3‐player (SD card required). Rotation of the switch will select one of the tracks on the SD card. The track will be displayed on the TFT. Once a track is selected, you can activate it by a single click.
Without rotation, the next track is selected.
After the triple click the player stops, as reading filenames will overload the SD card I/O.

A long click ( longer than 1 second ) will start playing random tracks from SD card.

After an inactivity of 4 seconds the rotary encoder will return to its default function (VOLUME).

Note: I experienced some issue's with response time. I'm not yet sure if this is caused by the added features that take up processor time ( like the spectrum analyzer and VU‐meter) or if I selected a input pin that is not optimal…I will figure this out in a next update. Honestly, I don't use it that much, other than volume control..

Brightness control ( Left knob)
You can use this knob for changing the intensity of the VU meter.

## 6.2. Browser interface

The browser interface has several screens that can be shown:

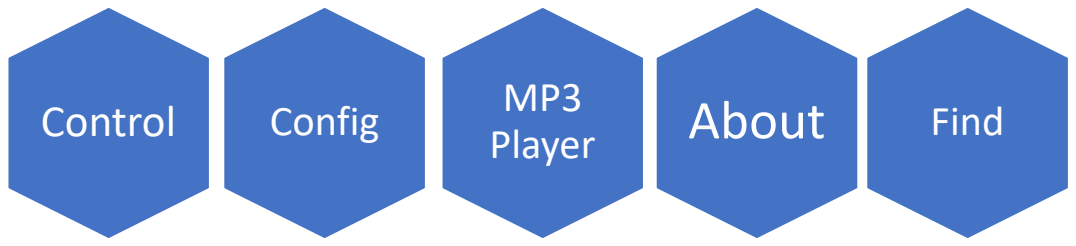
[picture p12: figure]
Control; Config; Player; About; Find

Control Screen

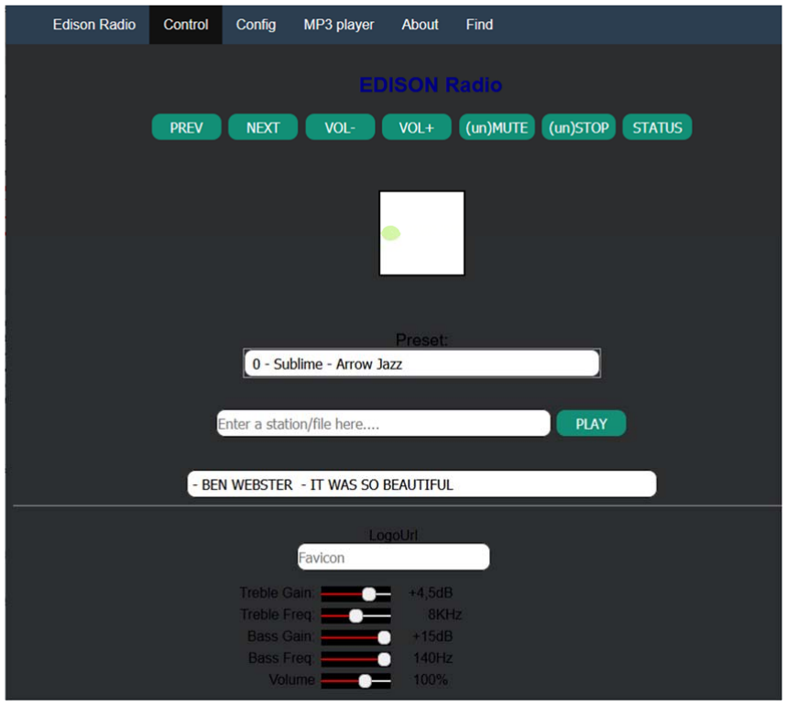
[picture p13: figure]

This is the screen for main operation. It has the following features:

- Change station to one from the preselected list
- Enter a link to a station manually
- Read back the information that the stream gives you like song title or station name
- See the logo of the station if available in the preselected list
- Adjust the volume, treble and bass
- Mute / unmute

By clicking on the Preset pulldown list, you can change to a pre‐selected station

The second input bar can be used to listen to a station by entering a weblink manually and pressing the play button

The third text bar will give you information about the song that is playing or whatever the radio station wants you to read.

The Favicon/Logourl textbar will be removed in a future update. The picture below the buttons will show you the stations Favicon if available. ( only for the first 8 presets)

This screen also lets you change volume, treble and gain settings by changing the sliders

Config Screen

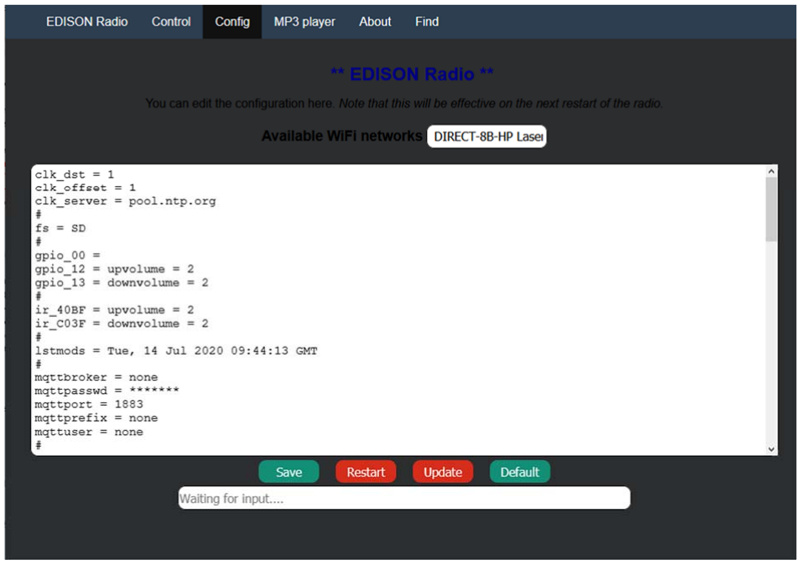
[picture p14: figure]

You can use this screen to adjust some important setting. Some settings should not be changed if you use the EDISON PCB but, if you are using your own setup it might be necessary. Some settings or functionalities are not used in this edition because I don't use them. However, most of the functionality that has to do with coding is still available if you configure them. I Didn't strip them from the original code as I only implemented new functions. So if needed you can reintroduce those functions if you like. For all the available functions, you best look at the documentation of the original code. You can find it here:

https://github.com/Edzelf/ESP32‐Radio/tree/master/doc

Some of the settings that are important for the EDISON edition of this radio are the following:

Settings for the IR receiver

You can link commands for the radio to any IR code by defining it in the configuration file:

Example:

ir_8A31 = uppreset = 1
ir_719A = station = us1.internet-radio.com:8105 ir_1F6B = mute

Settings for MQTT

Please take a look at the original coding documentation by ED:

https://github.com/Edzelf/ESP32‐Radio/tree/master/doc

Settings for Rotary encoder

The rotary encoder has a few settings that are fixed if you are using the EDISON PCB. However, if you prefer to switch left and right rotation ( clockwise vs counter clockwise) you can exchange the pins on: dt and clk

pin_enc_clk = 25 | # GPIO Pin number for rotary encoder CLK
pin_enc_dt = 26 | # GPIO Pin number for rotary encoder DT
pin_enc_sw = 27 | # GPIO Pin number for rotary encoder SW

Settings for TFT
Pre‐settings for stations and logo's
Preset for startup station Settings for WIFI

MP3 Screen

If you connect and configure the SD card correctly and it has MP3 Files stored on it, the Radio will scan this card during the boot sequence. You can play back a mp3 file by selecting it from the pull‐down menu. You can also play them using a random mode.

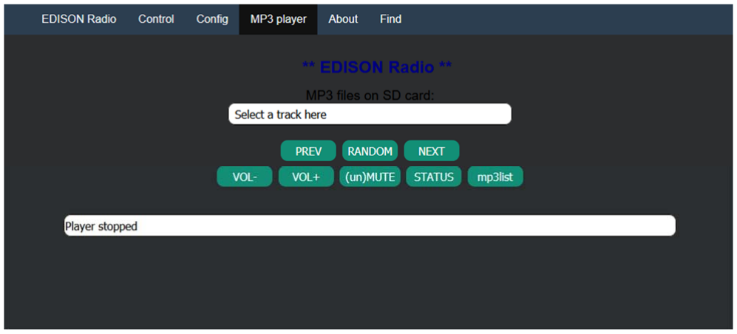
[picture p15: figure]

About Screen

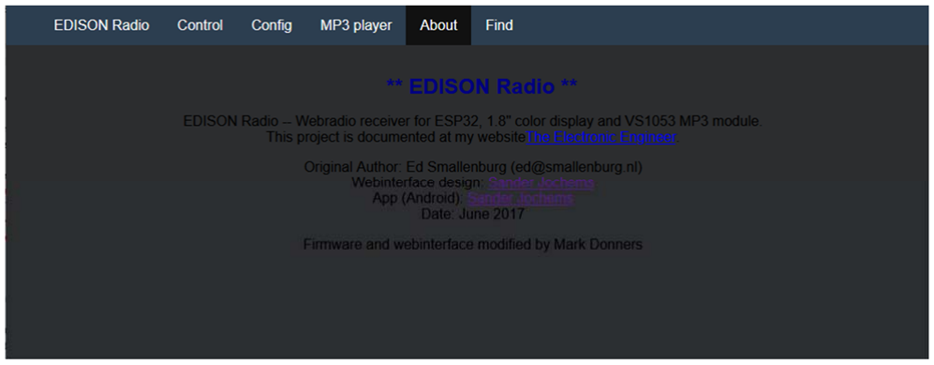
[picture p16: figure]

The about screen will give you some basic information and show you some credits and stuff

Find Screen

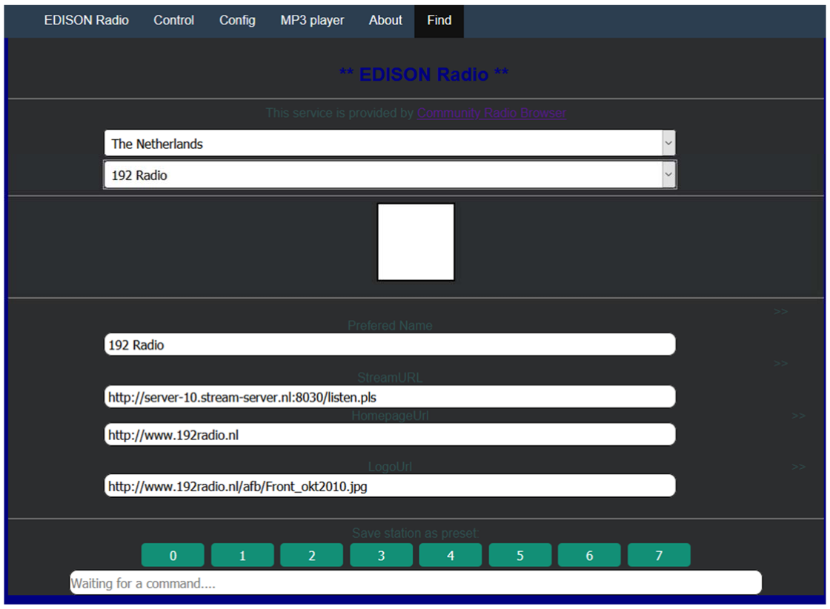
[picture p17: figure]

You can use this search engine to find online radio stations, filtered by country. If available, it will show you the streaming URL and the station logo. You can store any station to your pre‐selection list by clicking on the buttons at the bottom of the screen. The logo will also be stored. If you want to store more than 8 stations, you can enter the address of the station manually in the configuration file but the logo will not be visible for the stations with number 9 and higher.

## 7. Programming your ESP32

I used the Arduino IDE. It is freely available online and it does the job. However, I recently stumbled on something called Sloeber Beryllium which is a great tool that offers a much better compiler interface. However, it has a bit of a learning curve but I promise, it's worth it! Why don't you check it out? You can also use Visual Studio or some other great IDE. However, it is important to install the right library and it is best not to install what you don't need as it might give you errors when compiling.

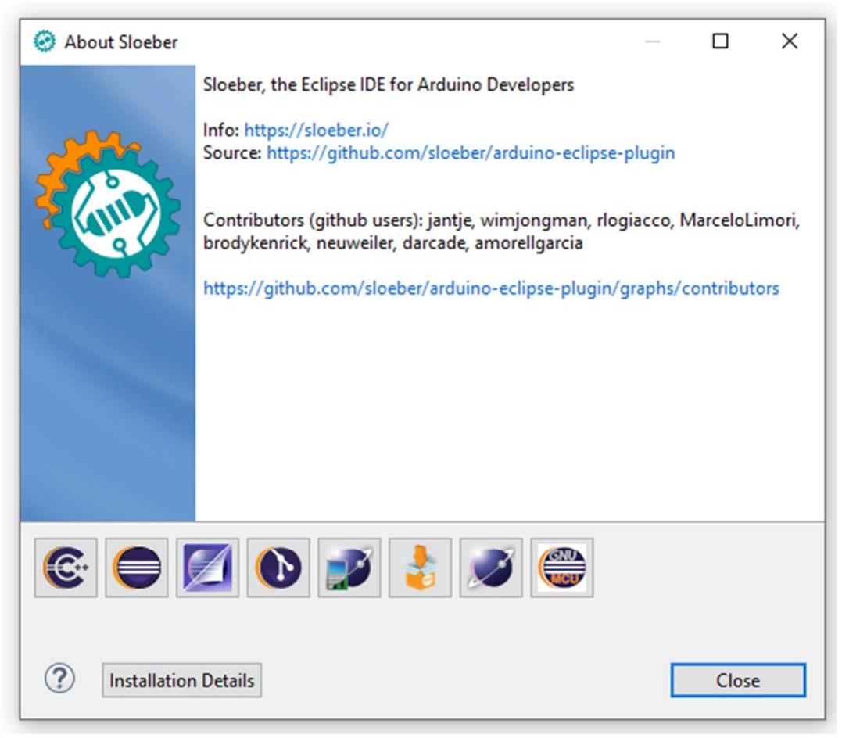
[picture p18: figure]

## 7.1. Here a few libraries that you'll need for sure:

C:\Users\chord\Documents\Arduino\libraries\PubSubClient

C:\Users\chord\AppData\Local\Arduino15\packages\esp32\hardware\esp32\1.0.4\libraries\SD

Using library Adafruit_NeoPixel at version 1.7.0 in folder: C:\Users\chord\Documents\Arduino\libraries\Adafruit_NeoPixel

Using library PubSubClient at version 2.6 in folder: C:\Users\chord\Documents\Arduino\libraries\PubSubClient

Using library WiFi at version 1.0 in folder: C:\Users\chord\AppData\Local\Arduino15\packages\esp32\hardware\esp32\1.0.4\libraries\WiFi

Using library ESPmDNS at version 1.0 in folder: C:\Users\chord\AppData\Local\Arduino15\packages\esp32\hardware\esp32\1.0.4\libraries\ESPmDNS

Using library SPI at version 1.0 in folder: C:\Users\chord\AppData\Local\Arduino15\packages\esp32\hardware\esp32\1.0.4\libraries\SPI

Using library ArduinoOTA at version 1.0 in folder: C:\Users\chord\AppData\Local\Arduino15\packages\esp32\hardware\esp32\1.0.4\libraries\ArduinoOTA

Using library Update at version 1.0 in folder: C:\Users\chord\AppData\Local\Arduino15\packages\esp32\hardware\esp32\1.0.4\libraries\Update

Using library Ethernet at version 2.0.0 in folder: C:\Program Files (x86)\Arduino\libraries\Ethernet

Using library Adafruit_ILI9341 at version 1.5.6 in folder: C:\Users\chord\Documents\Arduino\libraries\Adafruit_ILI9341

Using library Adafruit_GFX_Library at version 1.10.4 in folder: C:\Users\chord\Documents\Arduino\libraries\Adafruit_GFX_Library

Using library FS at version 1.0 in folder: C:\Users\chord\AppData\Local\Arduino15\packages\esp32\hardware\esp32\1.0.4\libraries\FS

Using library SD at version 1.0.5 in folder: C:\Users\chord\AppData\Local\Arduino15\packages\esp32\hardware\esp32\1.0.4\libraries\SD

Using library Adafruit_BusIO at version 1.7.1 in folder: C:\Users\chord\Documents\Arduino\libraries\Adafruit_BusIO

Using library Wire at version 1.0.1 in folder: C:\Users\chord\AppData\Local\Arduino15\packages\esp32\hardware\esp32\1.0.4\libraries\Wire

Remark: I had some trouble compiling when I started. Turned out that Arduino IDE had many libraries activated and it decided to choose the wrong ones whenever it had to choose between libraries. I solved it by uninstalling the Arduino IDE and re‐installing it from scratch.

## 7.2. Preparing the ESP32 to use the NVS WARNING: DO NOT SKIP THIS STEP IF YOU WANT A FUNCTIONAL RADIO

If you start by running the main program without running this little tool first, you will find yourself a radio that doesn't work. It won't start because it cannot find the table with settings that is stored in NVS, causing it to reboot…and.. reboot…and reboot…

So your first step should be to run the initialization tool. It is called Esp32_radio_init and you can find it in the project folder on GITHUB

https://github.com/donnersm/EdisonRadio/tree/main/ArduinoSketch/InitializeTool

You need to run it at least once. Do not worry about the content it puts in the NVS, you can change that later in the main program.

To run it, open the "Esp32_radio_init.ino" with your Arduino IDE ( of your own software if you prefer), upload it and start…You can monitor what it is doing by using your serial monitor.

## 7.3. Uploading the main program

The main program can be downloaded from GITHUB here:

https://github.com/donnersm/EdisonRadio/tree/main/ArduinoSketch/MainProgram

Open it with your Arduino IDE, compile and upload. If you used the same configuration as I did, then it should work without trouble. However, If you used a different display or you want to activate some of the disabled features, you'll need to adjust the code accordingly. If you can't get the information on how to do that from this document, I would suggest to check out the documentation of the original design that was done by Ed Smallenburg. You can find it here:

https://github.com/Edzelf/ESP32‐Radio/tree/master/doc

After uploading, there is a big change you will start hearing one of my favourite Jazz stations. Feel free to change them to your likings.

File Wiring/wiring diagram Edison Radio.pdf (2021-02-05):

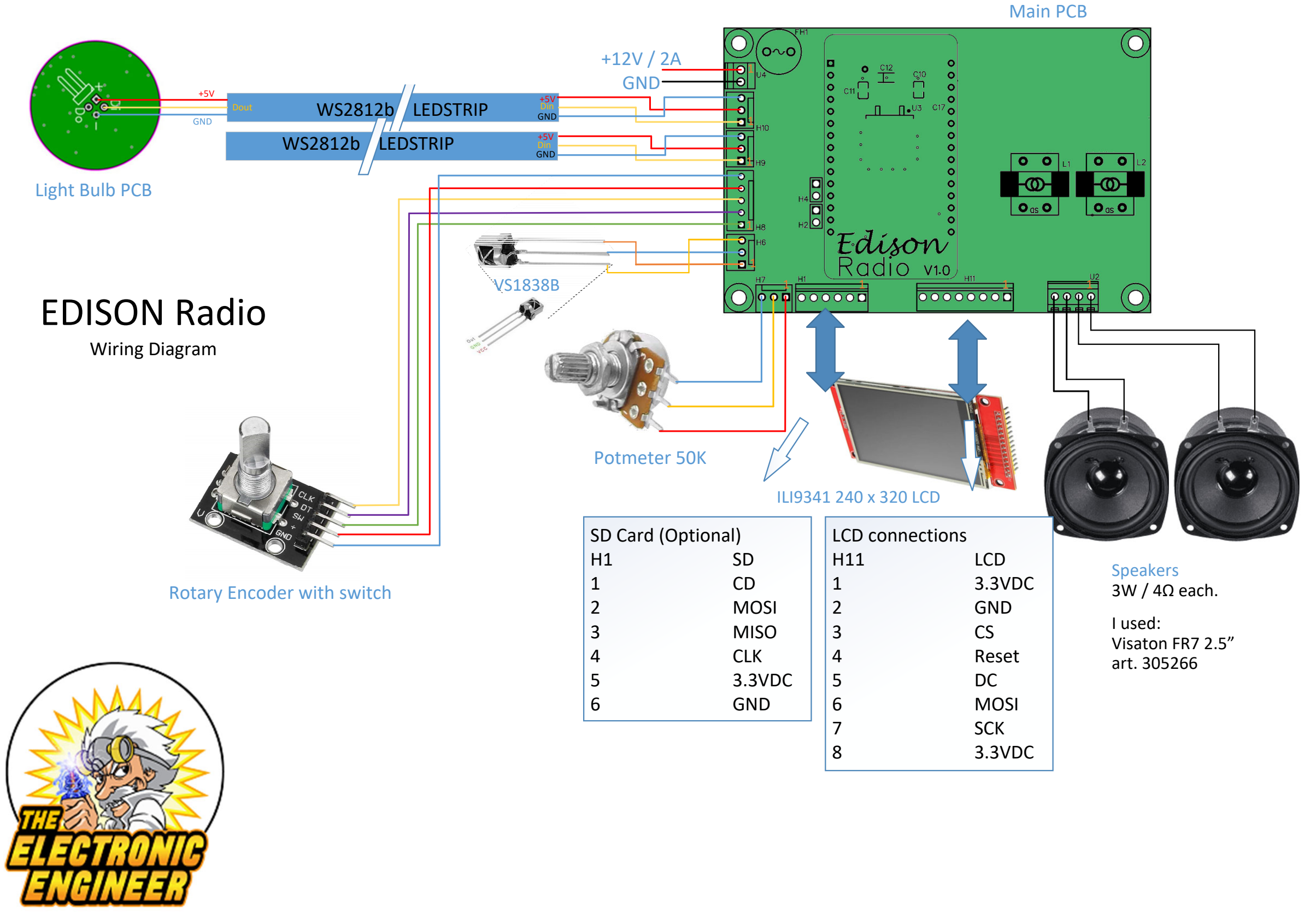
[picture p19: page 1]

SD Card (Optional)
H1 | SD
1 | CD
2 | MOSI
3 | MISO
4 | CLK
5 | 3.3VDC
6 | GND

+12V / 2A
GND
WS2812b LEDSTRIP

+5V

GND

Dout | Din +5V GND
WS2812b LEDSTRIP | Din +5V GND

VS1838B

LCD connections
H11 | LCD
1 | 3.3VDC
2 | GND
3 | CS
4 | Reset
5 | DC
6 | MOSI
7 | SCK
8 | 3.3VDC

1

1

1

1

1
1 | 1 | 1 | 1

ILI9341 240 x 320 LCD

Speakers
3W / 4Ω each.

I used:
Visaton FR7 2.5”
art. 305266

Rotary Encoder with switch

Light Bulb PCB

Main PCB

Potmeter 50K

# EDISON Radio

Wiring Diagram

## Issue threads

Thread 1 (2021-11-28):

error compiling

yo2ldk, 2021-11-28:
Hi,
  I found your nice project because I have KaRadio version, but I need something on Arduino code and yours is excellent
   Still, on compiling I have this error " variable or field 'setdatamode' declared void", and stop to
   void setdatamode ( datamode_t newmode );
   can you help me with taht please?
   I have all libraries..
   TNX in advance !

donnersm, 2021-11-28:
Are you using the ESP32?

yo2ldk, 2021-11-29:
sure..
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

donnersm, 2021-11-29:
I see, but u are using the esp wrover while i used the devkit v1. Try changing it and see if it compiles

yo2ldk, 2021-11-29:
Thank you Mark for reply and your time,
I try it with many models, result is the same error
maybe is linked with some library I have the latest, maybe need some olds version..
that it is, I will search more..

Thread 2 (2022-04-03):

Which partition scheme should be used for a 16MB ESP32 board?

dreamy1, 2022-04-03:
Hello,

thanks for this great work!

I am confused how to start with the arduino IDE with several partition schemes to choose, for a ESP32 devkit board there are following options e.g.:

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

Which option is the right one to choose?

Thanks,
Stefan

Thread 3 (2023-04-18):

unable to play MP3s on SDcard.

The-Valveman, 2023-04-18:
I have assembled this unit for incorporation into a receiver that i have built the radio function works perfectly but i am having problems playing MP3s on an SD card. I have tried various file formats either just putting the tracks in the root of the SD card or putting them in folders. when i try to select tracks from the drop down list all i get is "Select track" as a drop down and none of the tracks appear in this drop down list. when i put the tracks in the root they show on the long white bar just below the green buttons when i click the MP3 list button but they dont appear in the drop down list. when i put the MP3s in a folder the don't show in the white bar when i click the MP3 list button. when i use the serial monitor the folder name appears but it states "0 tracks on local drive. is there a specific format to the file structure on the SD card? there is no  mention in the manual as to the file format needed on the SD card. any help would be appreciated.

donnersm, 2023-04-19:
Looking at the serial monitor, it should say something like : SD Card init OK.   Or it will say something like Error SD Card….
However if it does say OK, and files are present in the root, it might be a library version isue..

Verstuurd vanaf mijn iPad

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

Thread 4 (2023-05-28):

No sound and no graphic equalizer on the screen

stefi01, 2023-05-28:
screen works but the equalizer stays as small blocks at the bottom of the screen but does flicker, like the blocks flash on and off and volume is full but if I turn the rotary encoder left or right by just one turn it goes to mute and a few more clicks and mute turns off, also no sound and the two transformers are the right way round, does mention an RMT error but I have no clue what that is, I am using all the standard parts for screen and encoder., Two of these boards were assembled, the other board does work but unfortunately is my room mate's who is a retired electrical engineer for the US Navy so I am pretty sure they assembled it right, same sketch uploaded to both boards, maybe a bad part installed somewhere? also, the rotary switch/knob does the same on both boards, clockwise or anti clockwise mute and unmute but no change to volume, no changes to the sketch were made
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
     Signal: -60 dBm
D: Scan Networks
D: Scan completed
D: Number of available networks: 4
D:  1 - TP-Link_BD34
, Encryption WPA2_PSK, Acceptable
D:  2 - TP-Link_BD34_EXT          Signal: -61 dBm, Encryption WPA_WPA2_PSK, Acceptable
D:  3 - Oaklandlove13             Signal: -74 dBm, Encryption WPA2_PSK,
D:  4 - Familia Garcia            Signal: -89 dBm, Encryption WPA2_PSK,
D: End of list
D: Command: clk_dst with parameter 1
D: Command: clk_offset with parameter 1
D: Command: clk_server with parameter pool.ntp.org
D: Command: gpio_00 with parameter uppreset = 1
D: Command: gpio_12 with parameter upvolume = 2
D: Command: gpio_13 with parameter downvolume = 2
D: Command: ir_40bf with parameter upvolume = 2
D: Command: ir_c03f with parameter downvolume = 2
D: Command: mqttbroker with parameter none
D: Command: mqttpasswd with parameter *******
D: Command: mqttport with parameter 1883
D: Command: mqttprefix with parameter none
D: Command: mqttuser with parameter none
D: Command: pin_enc_clk with parameter 26
D: Command: pin_enc_dt with parameter 25
D: Command: pin_enc_sw with parameter 27
D: Command: pin_ir with parameter 35
D: Command: pin_sd_cs with parameter 21
D: Command: pin_tft_cs with parameter 15
D: Command: pin_tft_dc with parameter 2
D: Command: pin_vs_cs with parameter 5
D: Command: pin_vs_dcs with parameter 16
D: Command: pin_vs_dreq with parameter 4
D: Command: preset with parameter 6
D: Command: preset_00 with parameter 109.206.96.34:8100
D: Command: preset_01 with parameter airspectrum.cdnstream1.com:8114/1648_128
D: Command: preset_02 with parameter us2.internet-radio.com:8050
D: Command: preset_03 with parameter airspectrum.cdnstream1.com:8000/1261_192
D: Command: preset_04 with parameter airspectrum.cdnstream1.com:8008/1604_128
D: Command: preset_05 with parameter us1.internet-radio.com:8105
D: Command: preset_06 with parameter icecast.omroep.nl:80/radio1-bb-mp3
D: Command: preset_07 with parameter 205.164.62.15:10032
D: Command: preset_08 with parameter skonto.ls.lv:8002/mp3
D: Command: preset_09 with parameter 94.23.66.155:8106
D: Command: preset_10 with parameter ihr/IHR_IEDM
D: Command: preset_11 with parameter ihr/IHR_TRAN
D: Command: toneha with parameter 0
D: Command: tonehf with parameter 0
D: Command: tonela with parameter 0
D: Command: tonelf with parameter 0
D: Command: volume with parameter 72
D: Slow SPI, Testing VS1053 read/write registers...
D: Fast SPI, Testing VS1053 read/write registers again...
D: endFillByte is 0
D: Connect to WiFi
D: Connected to TP-Link_BD34
D: IP = 192.168.0.157
D: Start server for commands
D: Network found. Starting mqtt and OTA
D: MDNS responder started
D: Rotary encoder is enabled
D: Sync TOD
D: Sync TOD, new value is 08:18:04
D: STOP requested
D: New preset/file requested (6/0) from icecast.omroep.nl:80/radio1-bb-mp3
D: Connect to new host icecast.omroep.nl:80/radio1-bb-mp3
D: Connect to icecast.omroep.nl on port 80, extension /radio1-bb-mp3
D: Song stopped incorrectly!
D: REG   Contents
D: ---   -----
D:   0 -   808
D:   1 -    40
D:   2 -     0
D:   3 -  6000
D:   4 -     0
D:   5 -  AC44
D:   6 -     0
D:   7 -  1814
D:   8 -     0
D:   9 -     0
D:   A -   D00
D:   B -  F8F8
D:   C -     0
D:   D -     0
D:   E -     0
D:   F -     0
D: Connected to server
D: Duration mp3loop 1
D: Switch to HEADER
D: Headerline: Server: Icecast
D: Headerline: Connection: Close
D: Headerline: Pragma: no-cache
D: Headerline: Expires: Thu, 19 Nov 1981 08:52:00 GMT
D: Headerline: Cache-Control: no-store, no-cache, private
D: Headerline: Content-Type: audio/mpeg
D: audio/mpeg seen.
D: Headerline: icy-br: 192
D: Headerline: ice-audio-info: samplerate=48000;channels=2;bitrate=192
D: Headerline: icy-genre: Talk
D: Headerline: icy-metadata: 1
D: Headerline: icy-name: NPO Radio1
D: Headerline: icy-pub: 0
D: Headerline: icy-url: http://www.radio1.nl
D: Headerline: icy-metaint: 16000
D: Switch to DATA, bitrate is 192, metaint is 16000
D: Duration mp3loop 48
D: Metadata block 144 bytes
D: Streamtitle found, 137 bytes
D: StreamTitle='NPO Radio 1 - Doodhoutkevers, de Europese Natuurbeschermingswet, klimaatsprookje Poppy en zangvogelcursus: Vink! - BNNVARA';
E (62287) rmt: rmt_driver_install(733): RMT driver already installed for channel
E (62289) rmt: rmt_wait_tx_done(847): RMT DRIVER ERR
E (62289) rmt: rmt_driver_uninstall(682): No RMT driver for this channel
D: Single click
D: Single click
D: Single click
D: Single click
D: Single click
D: Single click
D: Single click
D: Single click

stefi01, 2023-05-31:
fixed, osiloscope went nuts when hooked to the amp ic, was faulty

Closed 2023-05-31.

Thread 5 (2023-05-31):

SD card fails to initialize

stefi01, 2023-05-31:
So I managed to get everything working including the ir but the sd module fails, I tried the sd Card built into the ILI9341 2.8" screen that I used and works fine but no luck with the sd on the back so tried a 3.3v and a 5v stand alone module that you get with Arduino kits, still failed and not recognized, the wiring is correct, MOSI TO MOSI pin 23, MISO TO MISO pin 19, SCK pin 18, SD CS TO 21 and verified the pin in the config file,, just confused how the pins match and yet it fails to initialize.

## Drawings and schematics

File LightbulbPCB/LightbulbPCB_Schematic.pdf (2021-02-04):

Edison_light | blob:https://easyeda.com/2968babe-3f74-4a4b-9adb-16d323f67121

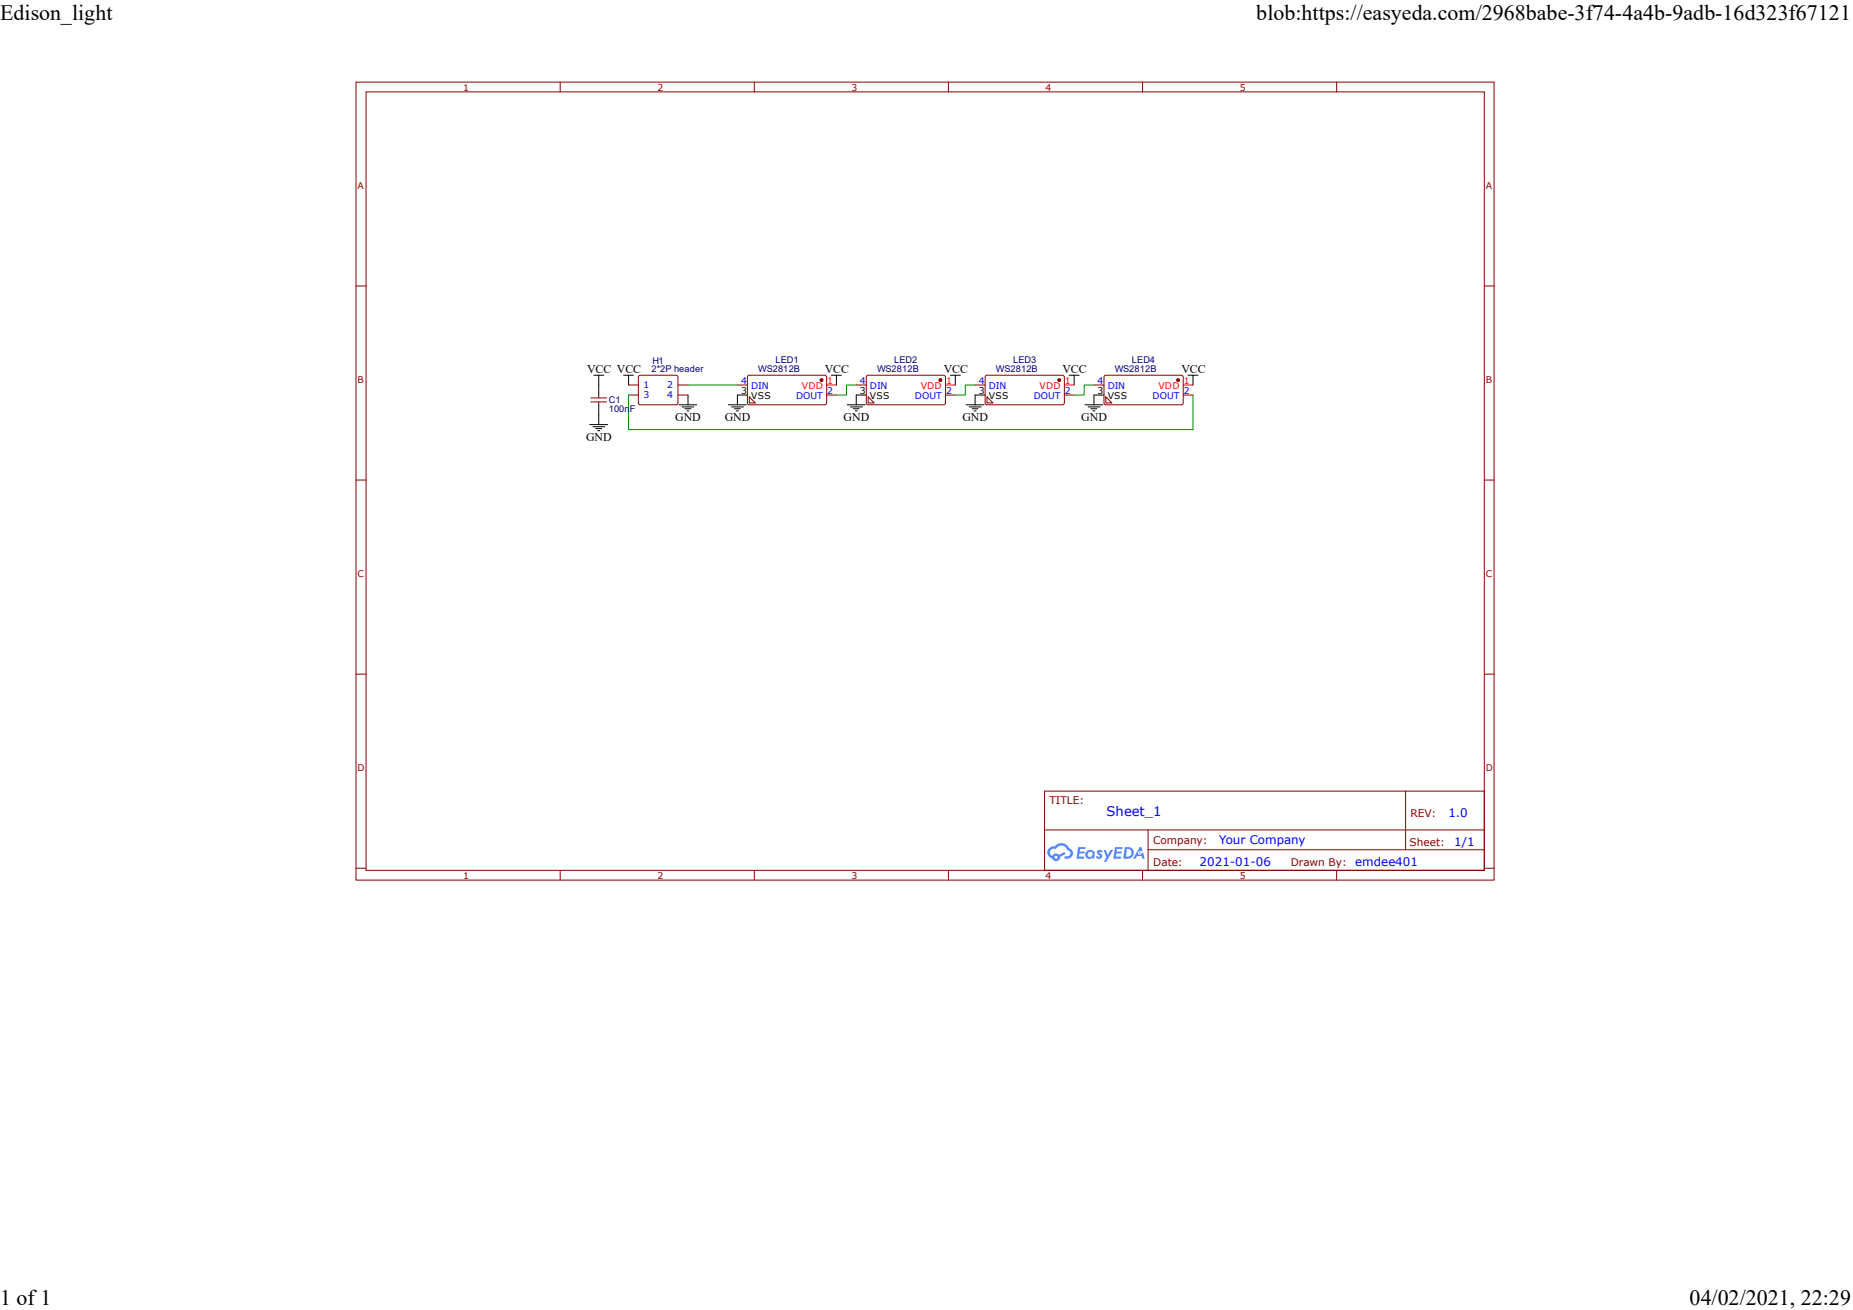
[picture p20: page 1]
TITLE:; Sheet_1; REV: 1.0; Date:; Sheet: 1/1 Drawn By: emdee401; LED1; DIN 4; VSS 3; DOUT 2; VDD 1; LED2; LED3; LED4; VCC; GND; 2*2P header; VCC VCC

Company: Your Company

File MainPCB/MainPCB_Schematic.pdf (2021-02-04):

## SD CARD INTERFACE

## SPEAKERS OUT

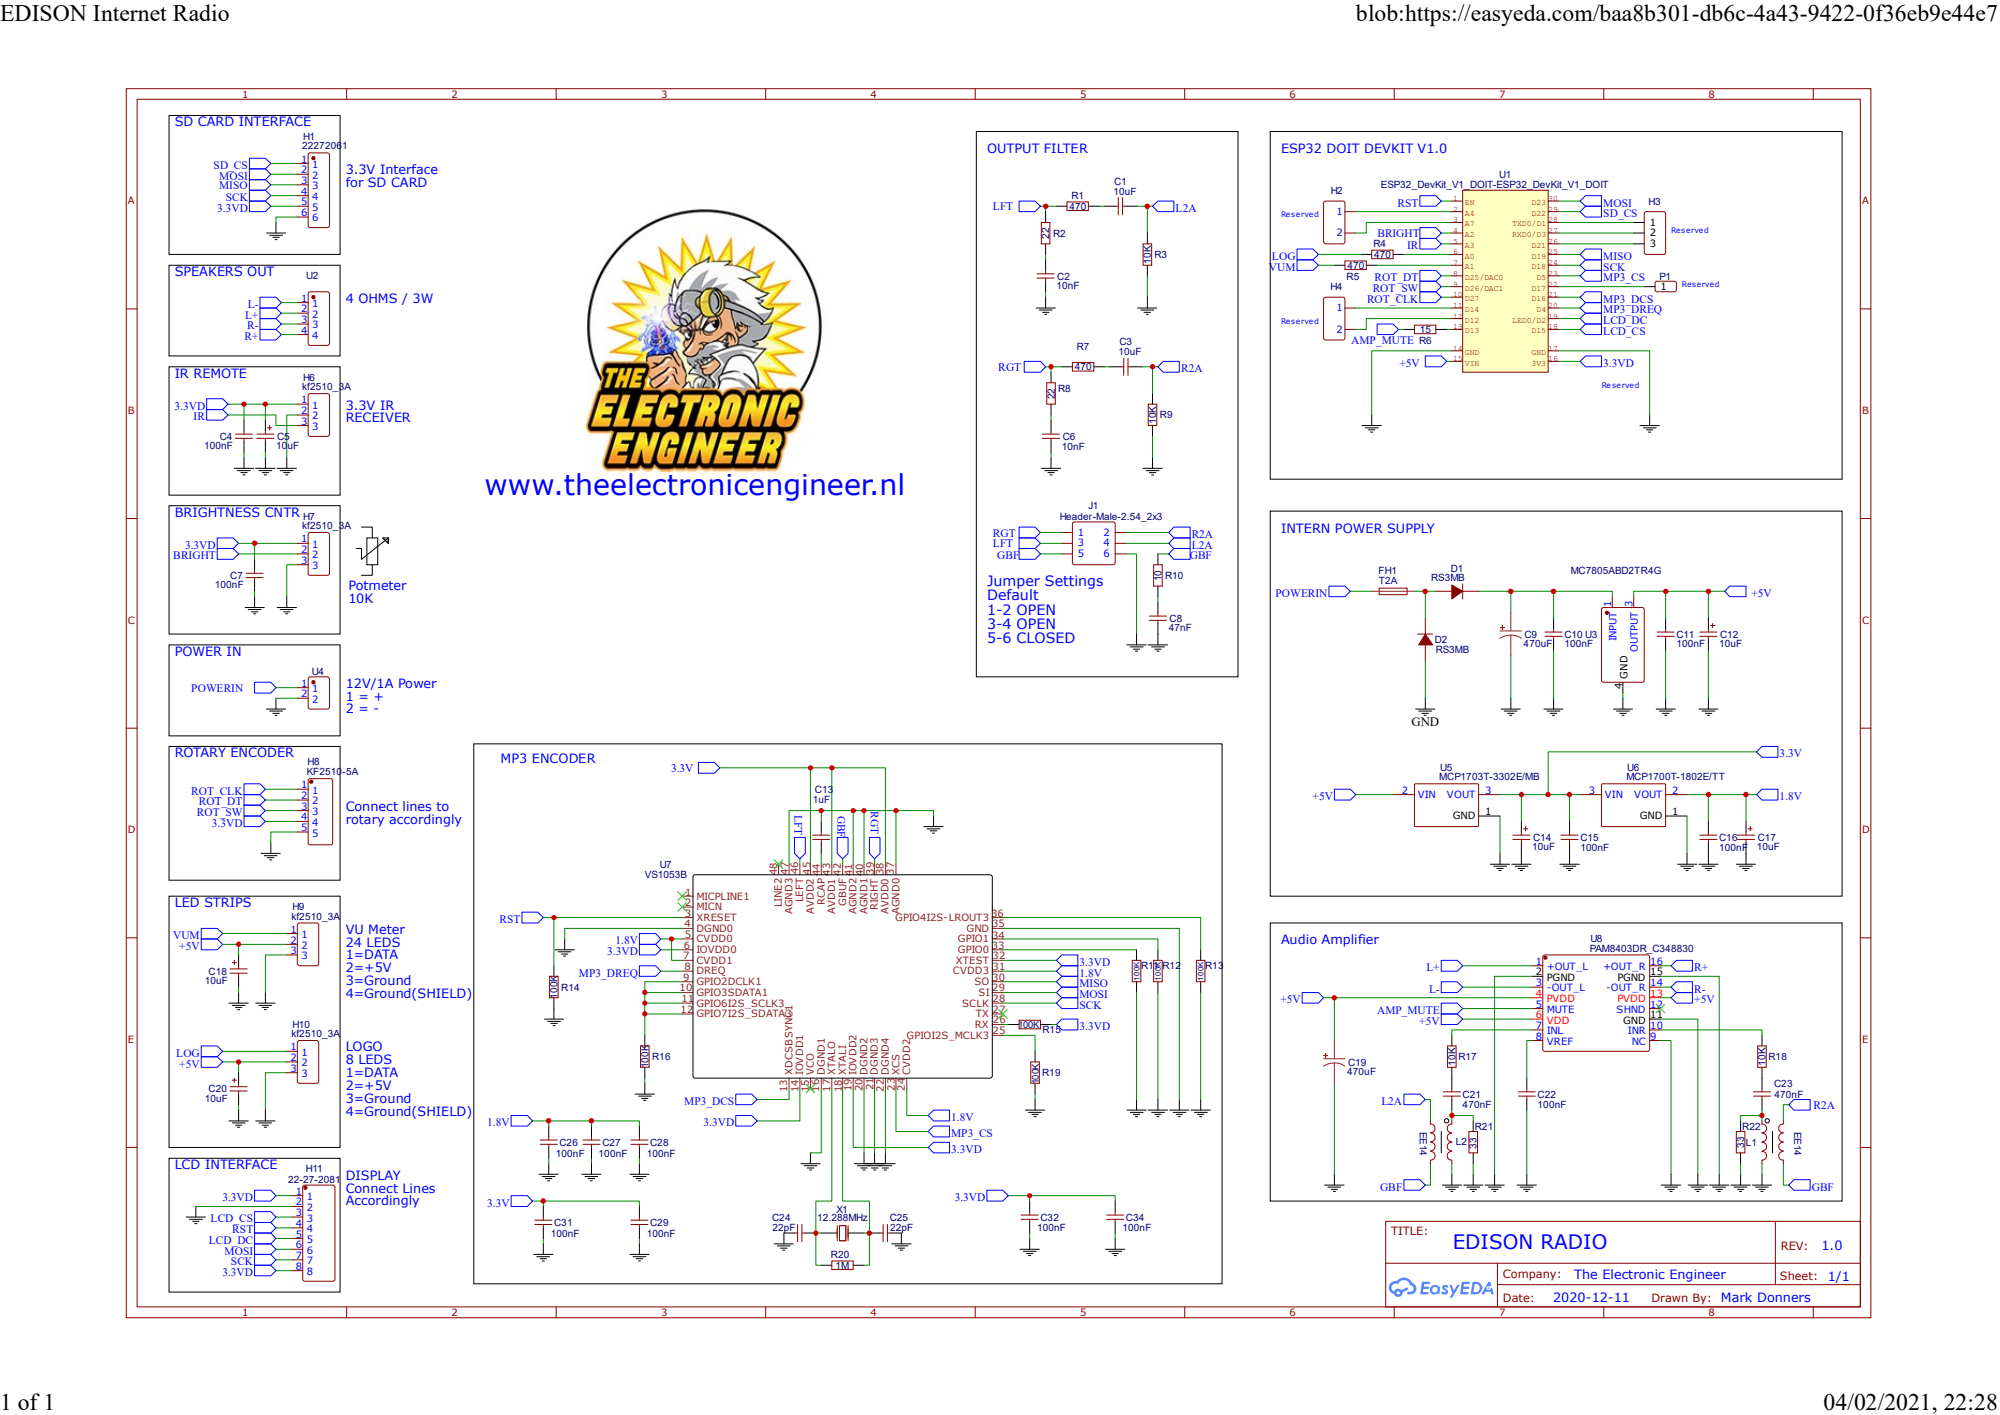
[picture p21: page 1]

Re served www.theelectronicengineer.nl

D26/DAC1 9 XDCSBSYNC1 13 IOVDD¹ 14 VCO 15 DGND¹ 16 XTALO 17 XTALI 18 IOVDD² 19 DGND² 20 DGND³ 21 DGND⁴ 22 XCS 23 CVDD² 24 GPIOI2S_MCLK3

100K R15 AGND⁰ ³⁷ AVDD⁰ ³⁸ RIGHT 39 AGND¹ ⁴⁰ AGND² ⁴¹ GBUF 42 AVDD¹ ⁴³ RCAP 44 AVDD² ⁴⁵ LEFT 46 AGND³ ⁴⁷ LINE2 48

SI 29 SO 30 CVDD3 31 XTEST 32 GPIO0 33 GPIO1 34 GND 35 GPIO4I2S-LROUT3 36

Company: The Electronic Engineer

Drawn By: Mark Donners

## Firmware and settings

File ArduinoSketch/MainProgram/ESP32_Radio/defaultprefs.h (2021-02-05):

// Default preferences in raw data format for PROGMEM
//
#define defaultprefs_version 1808016
const char defprefs_txt[] PROGMEM = R"=====(
# Example configuration
# Programmable input pins:
gpio_00 = uppreset = 1
gpio_12 = upvolume = 2
gpio_13 = downvolume = 2
gpio_14 = stop
gpio_17 = resume
gpio_34 = station = icecast.omroep.nl:80/radio1-bb-mp3
#
# MQTT settings
mqttbroker = none
mqttport = 1883
mqttuser = none
mqttpasswd = none
mqqprefix = none
# Enter your WiFi network specs here:
wifi_00 = SSID1/PASSWD1
wifi_01 = SSID2/PASSWD2
#
volume = 72
toneha = 0
tonehf = 0
tonela = 0
tonelf = 0
#
# Some preset examples preson = station log, preset= station url
precon_00 = https://i.postimg.cc/Z5w6Md75/Logo-Sublime-De-Leckere-Donkere-achtergrond.png
precon_01 = http://1047hit.com/wp/wp-content/uploads/2016/06/cropped-logo-270x270.png
precon_02 = https://i.postimg.cc/Z5w6Md75/Logo-Sublime-De-Leckere-Donkere-achtergrond.png
precon_03 = https://i.postimg.cc/Z5w6Md75/Logo-Sublime-De-Leckere-Donkere-achtergrond.png
precon_04 = https://l1.nl//static/meta/apple-touch-icon.png
precon_05 = https://upload.wikimedia.org/wikipedia/commons/thumb/d/da/NPO_Radio_1_logo_2014.svg/640px-NPO_Radio_1_logo_2014.svg.png
precon_06 = https://www.npo3fm.nl/templates/npo3fm/images/logo-npo3fm.png
precon_07 = http://www.themusicalbox.com.ar/favicon.ico
preset = 0
preset_00 = playerservices.streamtheworld.com/api/livestream-redirect/SUBLIMEARROWJAZZ.mp3   # 0 - Sublime - Arrow Jazz
preset_01 = s8.voscast.com:7528/;stream1483728563212/1 # 1 - 1047 Hit - San Jose
preset_02 = playerservices.streamtheworld.com/api/livestream-redirect/SUBLIMESMOOTH.mp3      # 2 - Sublime - Smooth
preset_03 = playerservices.streamtheworld.com/api/livestream-redirect/SUBLIMEPLAYGROUND.mp3?ver=78785 # 3 - Sublime Christmas
preset_04 = d34pj260kw1xmk.cloudfront.net/icecast/l1/radio-bb-mp3                            # 4 - L1 Radio
preset_05 = icecast.omroep.nl:80/radio1-bb-mp3                                               # 5 - NPO Radio 1
preset_06 = icecast.omroep.nl/3fm-bb-aac                                                     # 6 - NPO 3FM
preset_07 = albireo.shoutca.st:9740/stream # 7 - The Musical Box Radio
preset_08 = skonto.ls.lv:8002/mp3                                                            # 8 - Skonto 128k
preset_09 = 94.23.66.155:8106                                                                # 9 - *ILR CHILL and GROOVE
preset_10 = ihr/IHR_IEDM                                                                     # 10 - iHeartRadio IHR_IEDM
preset_11 = ihr/IHR_TRAN                                                                     # 11 - iHeartRadio IHR_TRAN
preset_12 = s2.netradiofm.com:6338                                                           # 12 - twitradioo#
# Clock offset and daylight saving time
clk_server = pool.ntp.org                            # Time server to be used
clk_offset = 1                                       # Offset with respect to UTC in hours
clk_dst = 1                                          # Offset during daylight saving time (hours)
# Some IR codes
ir_40BF = upvolume = 2
ir_C03F = downvolume = 2
# GPIO pinnings
pin_ir = 35                                          # GPIO Pin number for IR receiver VS1838B
pin_enc_clk = 26                                     # GPIO Pin number for rotary encoder "CLK"
pin_enc_dt = 25                                      # GPIO Pin number for rotary encoder "DT"
pin_enc_sw = 27                                      # GPIO Pin number for rotary encoder "SW"
#
pin_tft_cs = 15                                      # GPIO Pin number for TFT "CS"
pin_tft_dc = 2                                       # GPIO Pin number for TFT "DC"
#
pin_sd_cs = 21                                       # GPIO Pin number for SD card "CS"
#
pin_vs_cs = 5                                        # GPIO Pin number for VS1053 "CS"
pin_vs_dcs = 16                                      # GPIO Pin number for VS1053 "DCS"
pin_vs_dreq = 4                                      # GPIO Pin number for VS1053 "DREQ"
)=====" ;

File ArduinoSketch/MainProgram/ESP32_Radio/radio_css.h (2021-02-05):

// radio.css file in raw data format for PROGMEM
//
const char radio_css[] PROGMEM = R"=====(
body {
   background-color: #2c2d2f;
   font-family: Arial, Helvetica, sans-serif;
}

h1 {
   color: navy;
   margin-left: 20px;
   font-size: 150%
}

ul {
   list-style-type: none;
   margin: 0;
   margin-left: -10px;
   overflow: hidden;
   background-color: #2C3E50;
   position:fixed;
   top:0;
   width:100%;
   z-index:100;
}

li .pull-left {
   float: left;
}

li .pull-right {
   float: right;
}

li a {
   display: block;
   color: white;
   text-align: center;
   padding: 14px 16px;
   text-decoration: none;
}

li a:hover, a.active {
   background-color: #111;
}

.button {
   min-width: 80px;
   height: 30px;
   background-color: #128F76;
   border: none;
   color: white;
   text-align: center;
   text-decoration: none;
   display: inline-block;
   font-size: 16px;
   margin: 4px 2px;
   cursor: pointer;
   border-radius: 10px;
   white-space: nowrap;
}

.buttonr {background-color: #D62C1A;}

.select {
   width: 160px;
   height: 32px;
   padding: 5px;
   background: white;
   font-size: 16px;
   line-height: 1;
   border: 1;
   border-radius: 5px;
   -webkit-border-radius: 5px;
   -moz-border-radius: 5px;
   -webkit-appearance: none;
   border: 1px solid black;
   border-radius: 10px;
}

.selectw {width: 410px;}

input[type="text"] {
   margin: 0;
   height: 28px;
   background: white;
   font-size: 16px;
   appearance: none;
   box-shadow: none;
   border-radius: 5px;
   -webkit-border-radius: 5px;
   -moz-border-radius: 5px;
   -webkit-appearance: none;
   border: 1px solid black;
   border-radius: 10px;
}

input[type="text"]:focus {
  outline: none;
}

input[type=submit] {
  width: 200px;
  height: 40px;
  background-color: #128F76;
  border: none;
  color: white;
  text-align: center;
  text-decoration: none;
  display: inline-block;
  font-size: 16px;
  margin: 4px 2px;
  cursor: pointer;
  border-radius: 5px;
}

textarea {
  width: 80;
  height: 25;
  border: 1px solid black;
  border-radius: 10px;
  padding: 5px;
  font-family: Courier, "Lucida Console", monospace;
  background-color: white;
  resize: none;
})=====" ;
